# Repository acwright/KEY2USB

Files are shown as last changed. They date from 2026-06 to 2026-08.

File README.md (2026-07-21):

KEY2USB
=======

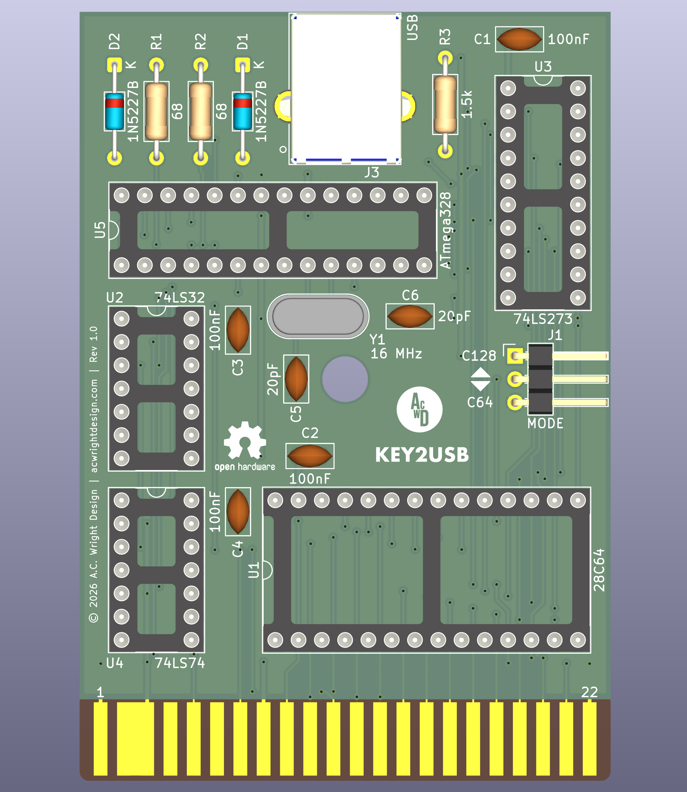
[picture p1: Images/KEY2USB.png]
KEY2USB


A non-invasive **Commodore 64** expansion port cartridge that lets the machine's own physical keyboard act as a **USB HID keyboard** for a connected PC running the VICE emulator. Plug it in, power on the C64, connect a USB cable — no case modification, no soldering into the keyboard.

---

## Table of Contents

- [Overview](#overview)
- [Compatibility](#compatibility)
- [Quick Start](#quick-start)
- [Architecture](#architecture)
- [Mode Jumper](#mode-jumper)
- [Hardware](#hardware)
  - [KEY2USB Board](#key2usb-board)
    - [Revision History](#revision-history)
- [Firmware](#firmware)
- [VICE Setup](#vice-setup)
  - [Joysticks](#joysticks)
  - [Verifying your setup](#verifying-your-setup)
  - [VIC-20 (xvic)](#vic-20-xvic)
- [Software](#software)
- [CAD](#cad)
- [Production](#production)
- [Schematics](#schematics)
- [Libraries](#libraries)
- [Bill of Materials](#bill-of-materials)
- [Purchase](#purchase)
- [License](#license)

---

## Overview

**KEY2USB** is a C64 cartridge that solves a specific problem: when running the VICE emulator on a PC alongside a real Commodore 64, you can't easily use the C64's authentic keyboard as a USB input device without modifying the machine. KEY2USB plugs into the expansion port and bridges the C64's keyboard matrix — read by the C64's own 6502 — to a USB HID keyboard interface, using no invasive hardware modifications.

Nothing inside the machine is touched. The cartridge takes over the C64 on power-up, scans the keyboard matrix itself, and reports every make/break to the PC as a standard USB HID boot keyboard. Power comes from the expansion port; the only cable is USB.

## Compatibility

| Machine | Supported | Notes |
|---|---|---|
| **Commodore 64** (all revisions) | Yes | Primary target |
| **Commodore 64C** | Yes | Identical keyboard matrix |
| **Commodore 128 / 128D** | Yes | Runs in C64 mode — see below. Verified on real hardware |
| **Ultimate 64** | Yes | Verified on real hardware |

On a **C128**, the cartridge asserts `/EXROM`, which the C128 detects at reset and
uses to boot straight into C64 mode — so KEY2USB comes up on its own with no key
combination needed. The full C128 keyboard is *not* scanned: the extra keys
(numeric keypad, ESC, TAB, ALT, HELP, and the separate cursor pad) sit outside the
standard 8×8 matrix and are not reported. Every key the C128 shares with the C64
works normally.

If a particular C128 does not autostart, power on while holding the **C=** key to
force C64 mode.

## Quick Start

1. With the C64 **powered off**, insert KEY2USB into the expansion port.
2. Connect the USB cable to your PC. The device enumerates as a standard HID
   keyboard — no drivers needed.
3. Power on the C64. The `KEY2USB` splash screen appears; the cartridge has taken
   over the machine and is scanning the keyboard.
4. In VICE, set **Settings → Keyboard → Keyboard Mapping → Positional**. This step
   is mandatory — see [VICE Setup](#vice-setup).
5. Type on the C64. Keystrokes arrive at the PC.

While KEY2USB is running, the C64 is dedicated to being a keyboard — it does not
return to BASIC. Power off and remove the cartridge to use the machine normally.

## Architecture

- **ROM side**: A 28C64 EEPROM holds two 4K firmware banks. The bank and `/EXROM` state are selected together by a single `MODE` jumper, set to **C64** on shipping units — see [Mode Jumper](#mode-jumper).
- **Glue logic**: A 74LS32 (quad OR gate) generates a write strobe from `/IO1` + `R/W`; a 74LS273 (8-bit D flip-flop register) latches the key-event byte the 6502 firmware writes to `$DE00`; a 74LS74 (dual D flip-flop) provides a single `RDY` handshake flag.
- **USB side**: An ATmega328P-PU runs the [V-USB](https://www.obdev.at/products/vusb/index.html) software USB stack, polls the latch via the `RDY` flag, and sends 8-byte USB HID boot-protocol keyboard reports. A 16 MHz crystal clocks the MCU.
- **USB front end**: Two 68Ω series resistors on D+ and D−, two 1N5227B (3.6V) Zener diodes to clamp the lines to spec, and a 1.5kΩ D− pull-up to +5V to signal a low-speed USB device — no 3.3V rail needed.
- **PCB constraint**: 100% through-hole / DIP — no SMD parts.

The two sides share only a single byte-wide latch and one ready flag — no shared clock or bus timing requirements.

## Mode Jumper

The board carries a 3-pin `MODE` header (J1) that selects the EEPROM bank and the
`/EXROM` state together:

| Jumper position | EEPROM bank | `/EXROM` | Behavior |
|---|---|---|---|
| **C64** (GND) — *factory default* | Lower 4K | Asserted | Autostarts via the `CBM80` signature. On a C128, forces a boot into C64 mode. |
| **C128** (+5V) | Upper 4K | Released | Autostarts as a C128 external function ROM in native mode. |

**Assembled cartridges ship with the jumper set to C64 and the case closed over
it.** The C64 bank is the supported configuration; it covers the C64, C64C, Ultimate 64, 
and the C128 by way of C64 mode. There is no need to change it, and the case has no opening for it.

The C128 bank is retained for developers and the curious. It is stable for the
standard 8×8 matrix — the same key coverage the C64 bank provides — but it offers
no advantage over C64 mode, since scanning of the C128-only extended keys is
incomplete and disabled. Changing the jumper means opening the case, and is
entirely at your own discretion.

## Hardware

This repository contains the KiCad 10.0 PCB design for the KEY2USB board.

### KEY2USB Board
`Hardware/`

A single cartridge PCB hosting the ROM, glue logic, and USB MCU. Provides:

- **ROM**: 28C64 EEPROM (DIP-28) preloaded with the keyboard-scan firmware
- **Write strobe**: 74LS32 quad OR gate — asserts `WRSTB` from `/IO1` + `R/W`
- **Key-event latch**: 74LS273 octal D flip-flop register — captures the byte written to `$DE00`
- **Handshake flag**: 74LS74 dual D flip-flop — one half as the `RDY`/`/CLRRDY` flag
- **USB MCU**: ATmega328P-PU (DIP-28) running V-USB, reads the latch, emits USB HID reports
- **Crystal**: 16 MHz THT crystal + 2× 20pF load capacitors
- **USB front end**: USB Type B connector, 68Ω series resistors, 1N5227B Zener clamps, 1.5kΩ D− pull-up
- **Mode select**: 3-pin 2.54mm jumper header — set to C64 at the factory (GND, asserts `/EXROM`, lower 4K EEPROM bank); see [Mode Jumper](#mode-jumper)
- **Bus connection**: 44-pin C64 expansion port edge connector
- **Power**: Drawn from the C64's own +5V via the expansion port

#### Revision History

**Rev 1.0**

- Initial release.

## Firmware

Both firmwares are implemented in `Firmware/` (see `Firmware/README.md` for build,
flash, and layout details). Set VICE's keyboard mapping to **Positional** — see
[VICE Setup](#vice-setup).

**6502 side (C64 bank — the shipping configuration):**
- Autostart via the `CBM80` signature, take over the machine, and draw a centered `KEY2USB` splash on the 40-column screen.
- Scan the 8×8 keyboard matrix directly via CIA #1 (`$DC00`/`$DC01`) for raw make/break events and modifier state — no KERNAL buffer.
- Scan **both joystick ports** on the same CIA #1 ports (they share the matrix lines, so no extra hardware is involved).
- On any key or joystick state change, write a one-byte event to `$DE00`.

The upper bank holds the C128 native-mode firmware, which autostarts from a
`CBM` / `$01` external function ROM header and scans the same 8×8 matrix. Extended-key
scanning via `$D02F` is present in the source but gated behind a build flag and not
compiled in — it is unverified on hardware. See `Firmware/Cart/README.md`.

**ATmega328/328P side:**
- Poll `RDY`; on set, read the key byte from `PINC`/`PINB`, pulse `/CLRRDY`.
- Run V-USB (low-speed USB 1.1); translate to USB HID usages and send an 8-byte boot-protocol keyboard report.
- Configured as a self-powered USB device.

## VICE Setup

One setting trips people up every time, so set it before anything else:

- **Keyboard mapping must be Positional, not Symbolic.** In VICE:
  **Settings → Keyboard → Keyboard Mapping → Positional**. This is the single
  most common first-time setup mistake — if keys look wrong, check this first.
  The reason is worth understanding, because it explains the whole signal path:

  A USB keyboard never transmits characters. Press `A` and it sends HID usage
  `0x04`; the USB spec names that "Keyboard a and A", but the name is only
  documentation — the code means *"the key where a US keyboard has A"*. Your OS
  decides it is an `A` by applying the selected layout. On AZERTY the same key
  sends the same `0x04` and the OS renders `Q`.

  KEY2USB is positional end to end for exactly that reason. The 6502 detects a
  key by matrix position (`col*8 + row`) and never computes a character; the
  ATmega looks that keyID up in `keymap.h` and emits the HID usage for the PC key
  in the corresponding physical spot; VICE's Positional keymap maps PC positions
  back onto C64 matrix positions. Positions in, positions through, positions out
  — nothing resolves to a character until VICE finally does it.

  Symbolic breaks that chain by inserting a translation. Press **SHIFT + 2**,
  which is `"` on a C64. The cartridge sends shift plus the position code for
  `2`; the host applies its US layout and concludes you typed `@`. Symbolic then
  asks "which C64 key produces `@`?" and presses that one — wrong. Positional
  ignores the character entirely, sees "physical shift + physical 2", and gives
  you the `"` you actually pressed. The keystroke arrived correctly either way;
  Symbolic just did an unwanted extra translation using a PC layout that does
  not match a C64's.
- USB HID reports are sent as a standard boot-protocol keyboard — no special
  VICE driver or configuration is needed beyond the keymap.

### Joysticks

Both joystick ports are scanned by the cartridge and arrive at the host as
**ordinary keystrokes**, so VICE has to be told which keys mean "joystick".
Everything lives on the numeric keypad, split so the two ports cannot collide:

**Port 2** — the easy one, no configuration at all:

> **Settings → Joystick → Joystick Port #2 → Numpad**

VICE's built-in Numpad device already maps keypad digits (`8/2/4/6` for
directions, `7/9/1/3` for diagonals, `0`/`5` for fire), and the cartridge's
port-2 mapping was chosen to match it exactly.

**Port 1** — needs a keyset, because Numpad can only serve one port:

> **Settings → Joystick → Joystick Port #1 → Keyset A**, then
> **Configure Keyset A**:

| Direction | Key |
|---|-----|
| North | Keypad **−** |
| South | Keypad **+** |
| West  | Keypad **/** |
| East  | Keypad **&ast;** |
| Fire  | Keypad **enter** |

Port 1 uses keypad *symbols* rather than digits or function keys for two
reasons: the digits are already claimed by the Numpad device serving port 2,
and the function-key row proved unreliable — F12 was silently undeliverable on
a macOS + GTK3 VICE host, with no identifiable cause. The symbols are untouched
by both.

### A caveat worth knowing

A held joystick direction grounds a line in the keyboard matrix, so it also
**phantom-presses real keys** — exactly as it does on a real C64. This is
inherent to the wiring, not a firmware choice, and it is left in place so the
cartridge behaves like the bare machine.

It hits **port 1** hardest: a held direction grounds a matrix *row*, pressing
all 8 keys in it — which includes RETURN, INST/DEL and CLR/HOME. Expect stray
keystrokes while a port-1 direction is held. **Port 2 is the one to use in
practice**; it grounds a column instead, which only aliases if you are also
pressing a key in that same column.

### Verifying your setup

`Software/key2usbtest.prg` shows live joystick state for both ports plus the
last keys received, so you can confirm the cartridge and your VICE
configuration in one place. See [Software/](Software/).

### VIC-20 (`xvic`)

The cartridge also drives VICE's VIC-20 emulator, with the same **Positional**
setting and no keymap changes. This works because VICE's two positional keymaps
are the same map in different coordinates — `VIC20/gtk3_pos.vkm` states the
relationship outright:

    # to convert from C64 to VIC20:
    # change rows 7 -> 0, 0 -> 7
    # change columns 7 -> 3, 3 -> 7

Applying that permutation and diffing the two files (VICE 3.x, GTK3, US layout)
gives:

| | |
|---|---|
| Host keysyms in each map | 151 / 151 |
| Present in one but not the other | 0 |
| Agree under the permutation | 150 |
| Differ | 1 |

The lone difference is cosmetic: `>` sits at matrix position `5 4` in both, but
carries shiftflag `1` on the C64 ("combined with shift") and `8` on the VIC-20
("can be shifted or not"). The cartridge sends the physical `.` key and physical
SHIFT as separate events, so both yield `>` regardless. The RESTORE entries
(`Page_Up` / `F12` / `Prior`) and all twenty joyport keypad entries are identical.

Both emulators therefore consume the same host keys and route them to the
same-labelled machine keys. `keymap.h` is built as the inverse of the C64
positional map, which makes it equally the inverse of the VIC-20 one.

Two caveats:

- This was established by comparing the shipped keymap files, not by a hardware
  session on `xvic`. The mapping is confirmed; end-to-end behaviour is not.
- **The VIC-20 has only one control port.** Point the cartridge's port-2 mapping
  (the keypad digits, via the Numpad device) at it; the port-1 keyset has nothing
  to connect to.

## Software
`Software/`

Host-side test software. `key2usbtest.prg` runs inside VICE and shows live
joystick state for both ports plus the last keystrokes received, so you can
verify a cartridge and your VICE configuration in one place. Build with
`make` (requires `petcat`, which ships with VICE) or use the prebuilt `.prg`.
See [Software/README.md](Software/README.md).

## CAD
`CAD/`

3D models and render images for the KEY2USB board.

## Production
`Production/`

JLCPCB-ready fabrication files, BOM, and component positions for PCB fabrication.

## Schematics
`Schematics/`

PDF schematic for the KEY2USB board.

## Libraries
`Libraries/`

Custom KiCad symbol and footprint libraries, including the C64 expansion port edge connector footprint and the USB Type B connector footprint.

## Bill of Materials

| Reference | Qty | Value | Description | Digikey |
|---|-----|---|---|---|
| C1, C2, C3, C4 | 4 | 100nF | Ceramic disc capacitor — IC bypass | [478-5732-ND](https://www.digikey.com/en/products/filter?keywords=478-5732-ND) |
| C5, C6 | 2 | 20pF | Ceramic disc capacitor — crystal load | [478-7724-ND](https://www.digikey.com/en/products/filter?keywords=478-7724-ND) |
| D1, D2 | 2 | 1N5227B | 3.6V Zener diode, DO-35 — USB line clamp | [1N5227B-ND](https://www.digikey.com/en/products/filter?keywords=1N5227B-ND) |
| J1 | 1 | MODE | 3-pin 2.54mm header + jumper cap — mode select, factory-set to C64 | [S1121EC-03-ND](https://www.digikey.com/en/products/filter?keywords=S1121EC-03-ND) |
| J2 | 1 | C64 EXP PORT | C64 expansion port edge connector (44-pin, 3.96mm pitch) | |
| J3 | 1 | USB | USB Type B connector, through-hole (UJ2-BH-BL1-TH) | [102-5886-ND](https://www.digikey.com/en/products/filter?keywords=102-5886-ND) |
| R1, R2 | 2 | 68Ω | Resistor, 1/4W — USB D+ / D− series | [S68CACT-ND](https://www.digikey.com/en/products/filter?keywords=S68CACT-ND) |
| R3 | 1 | 1.5kΩ | Resistor, 1/4W — USB D− pull-up to +5V | [S1.5KCACT-ND](https://www.digikey.com/en/products/filter?keywords=S1.5KCACT-ND) |
| U1 | 1 | 28C64 | 8K×8 EEPROM, DIP-28 — holds C64 and C128 firmware banks | [AT28C64B-15PU-ND](https://www.digikey.com/en/products/filter?keywords=AT28C64B-15PU-ND) |
| U2 | 1 | 74LS32 | Quad 2-input OR gate, DIP-14 — generates write strobe | [296-1658-5-ND](https://www.digikey.com/en/products/filter?keywords=296-1658-5-ND) |
| U3 | 1 | 74LS273 | 8-bit D flip-flop register, DIP-20 — key-event latch | [296-1657-5-ND](https://www.digikey.com/en/products/filter?keywords=296-1657-5-ND) |
| U4 | 1 | 74LS74 | Dual D flip-flop, DIP-14 — RDY handshake flag | [296-1668-5-ND](https://www.digikey.com/en/products/filter?keywords=296-1668-5-ND) |
| U5 | 1 | ATmega328P-PU | 8-bit AVR MCU, DIP-28 — V-USB and HID firmware | [ATMEGA328-PU-ND](https://www.digikey.com/en/products/filter?keywords=ATMEGA328-PU-ND) |
| Y1 | 1 | 16 MHz | Crystal, through-hole — ATmega328P clock | [3155-16M20P2/49US-ND](https://www.digikey.com/en/products/filter?keywords=3155-16M20P2/49US-ND) |

## Purchase

KEY2USB is available as a kit on Tindie for those who would rather not order
boards from a fab and source parts themselves.



## License

Hardware designs are released under the [CERN Open Hardware Licence Version 2 – Permissive](https://ohwr.org/cern_ohl_p_v2.txt).

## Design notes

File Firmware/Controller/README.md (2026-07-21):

KEY2USB — Controller (ATmega328/328P)
=====================================

Bare-metal AVR firmware that turns the KEY2USB cartridge into a **USB HID boot
keyboard** using [V-USB](https://www.obdev.at/products/vusb/). It reads C64/C128
key events from the 74LS273 latch (gated by the `RDY` flag), translates each
`keyID` to a USB HID usage, and sends 8-byte boot-keyboard reports.

Why bare-metal (no Arduino)
---------------------------
V-USB bit-bangs USB in software and needs tight, deterministic interrupt timing.
This is a frameworkless `avr-gcc` build. The V-USB stack is vendored in
`lib/usbdrv/`; the project config is `include/usbconfig.h`.

Layout
------
    include/usbconfig.h   V-USB configuration (HID boot keyboard, D+ = PD2/INT0)
    src/main.c            report loop, latch handshake, HID descriptor
    src/protocol.h        event-byte contract + pin helpers (mirrors Cart.inc)
    src/keymap.h          keyID -> HID usage table (editable)
    lib/usbdrv/           vendored V-USB
    fuses.cfg             fuse values for a 16 MHz crystal

Build & flash (PlatformIO)
--------------------------
    pio run                    # build (default env: atmega328)
    pio run -e atmega328p      # build for a 328P
    pio run -t upload          # flash CODE via minipro (uses the env's chip)

`platformio.ini` defaults to **atmega328** (the non-P chip on the test PCB).
Upload writes program memory **and** the fuses (`fuses.cfg`) each time, so a
fresh chip is fully configured in one `pio run -t upload`.

Fuses (one-time)
----------------
For a 16 MHz crystal, no bootloader, ISP enabled, BOD off:

| Fuse  | Value | Meaning |
|---|---|---|
| LFUSE | `0xFF`| low-power crystal 8–16 MHz, slow rising power, CKDIV8 off |
| HFUSE | `0xDF`| SPIEN on, no bootloader (BOOTRST=1), reset enabled |
| EFUSE | `0xFF`| brown-out detector disabled |
| LOCK  | `0xFF`| unlocked |

`fuses.cfg` holds these in minipro's config format (keys `lfuse`/`hfuse`/`efuse`/
`lock`). **The critical one is LFUSE**: a factory-fresh 328 ships at `0x62`
(internal 8 MHz RC ÷8 = 1 MHz) and must become `0xFF` for the external 16 MHz
crystal, or V-USB will not run.

    # optional: read current values (also confirms the file format)
    minipro -p "ATMEGA328@DIP28" -c config -r current.cfg
    # write the fuses
    minipro -p "ATMEGA328@DIP28" -c config -w fuses.cfg

minipro drives the ZIF socket directly, so it can still reprogram a chip whose
fuses select the external crystal — setting LFUSE=0xFF is not a lock-out.

USB identity
------------
Uses obdev's free shared VID/PID for HID-class devices: `0x16c0/0x27db`
(product string `KEY2USB`). Fine for personal use; see V-USB's
`USB-IDs-for-free.txt` for the rules.

The keymap
----------
`src/keymap.h` maps each `keyID` to a USB HID usage:

- `0x00`      — ignored
- `0x01..0xDF`— normal key (placed in the 6-key report array)
- `0xE0..0xE7`— modifier (Left Ctrl … Right GUI), OR-ed into the modifier byte

The defaults are the **inverse of VICE's stock C64 positional keymap**
(`gtk3_pos.vkm`), and that inversion is the whole design of this table: a HID
usage is itself a *position* (`0x04` means "the key where a US keyboard has A",
not the letter A), so each entry answers "which PC key sits where this C64 key
sits?" — never "which character does this key type?". VICE's **Positional**
keymap then maps those PC positions back onto C64 matrix positions and the
round trip closes. Symbolic breaks it by translating to characters through a PC
layout; see the top-level README's [VICE Setup](../../README.md#vice-setup).

Non-obvious defaults that match VICE positional:

    C64 CTRL  -> HID Tab          C64 C=        -> HID Left Ctrl (modifier)
    C64 R/S   -> HID Escape       C64 CLR/HOME  -> HID Home
    C64 £     -> HID End          C64 =         -> HID Page Down
    C64 up    -> HID '\'          C64 left      -> HID '`'

Edit the table freely for other hosts/emulators. keyIDs 64–87 (C128 extended
keys) are unmapped by default — see the Cart README to enable that scan.

Joysticks
---------
Both joystick ports are scanned by the cartridge and arrive as ordinary key
events, so the host just sees keystrokes. Defaults:

| Port | keyIDs | Up | Down | Left | Right | Fire |
|---|---|----|---|---|---|---|
| 2 | 112–116| Keypad 8 | Keypad 2 | Keypad 4 | Keypad 6 | Keypad 0 |
| 1 | 120–124| Keypad − | Keypad + | Keypad / | Keypad &ast; | Keypad enter |

Port 1 avoids the function-key row because **F12 proved undeliverable on a
macOS + GTK3 VICE host** (verified 2026-07-19: F8–F11 all registered, F12 never
did — including pressed directly on the host keyboard with the cartridge
unplugged). The standard-function-keys setting, macOS symbolic hotkeys, VICE's
hotkey files and the SDL menu key were all ruled out; the root cause was never
found, so port 1 steers clear of that row entirely.

Keypad **digits** are equally unusable: VICE's Numpad device — the port-2
setting — claims KP 7/9/1/3 for diagonals and KP 0/5 for fire, so digits would
cross-trigger between the two ports. Only the symbols are free, and they sit
sensibly on the pad (`/` left of `*`, `−` above `+`).

Point VICE at them with **Settings → Joystick → Keyset A / Keyset B**, then
assign the keyset to the emulated port.

Both sets use usages that **no matrix key can produce**, which is deliberate.
A held port-1 direction grounds a row line and phantom-presses all 8 keys in
that row, so an earlier mapping to `W/S/A/D` was indistinguishable from the
stick's own crosstalk — pressing left emitted `A, D, G, J, L`, which is exactly
row 2 of the C64 matrix. F8–F12 and the keypad never appear in the keyboard
table above, so they are unambiguous.

Two things to know:

- **Keypad usages can depend on NumLock** on some hosts. If port 2 misbehaves,
  either switch NumLock on or retarget those five entries.
- The HID boot keyboard reports **6 non-modifier keys at once**, and
  `keyDown()` silently drops past six. This is why the cartridge scans the
  joysticks *before* the matrix: a held port-1 direction generates 8 phantom
  key events, which would otherwise claim every slot and starve the real
  joystick event. Port 1 remains inherently noisy — the phantoms are genuine
  C64 behaviour — so port 2 is the one to use in practice.

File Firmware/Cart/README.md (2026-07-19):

KEY2USB — Cartridge ROM (6502)
==============================

Autostart ROM for the KEY2USB expansion-port cartridge. It takes over the
C64/C128, shows a `KEY2USB` splash, then continuously scans the CIA#1 keyboard
matrix and both joystick ports, writing a make/break **event byte** to `$DE00`
(`/IO1`) on every transition. The 74LS273 latches the byte and the 74LS74 raises
`RDY` for the ATmega328 controller.

Two banks, one source
---------------------
The 28C64 (8K) is split by the `MODE` switch, which drives EEPROM `A12`:

| MODE | A12 | Bank | Autostart |
|---|-----|---|---|
| GND | 0 | lower 4K  | C64 (`CBM80`, forces C128 into C64 mode) |
| +5V | 1 | upper 4K  | C128 (function-ROM `CBM` signature) |

`Cart.asm` is assembled twice (the C128 build passes `--asm-define TARGET_C128`)
and the two 4K images are concatenated into the 8K `Cart.bin`. Only bus
`A0..A11` reach the EEPROM, so each 4K bank mirrors across the `$8000-$9FFF`
ROML window.

Build
-----
Requires [cc65](https://cc65.github.io/) (`cl65` on PATH).

    make            # -> Cart.bin (8192 bytes)
    make view       # hexdump Cart.bin
    make clean

Program the EEPROM
------------------
    make eeprom     # build, then program the AT28C64B via minipro

`make eeprom` runs `minipro -p "AT28C64B" -w Cart.bin`. Use minipro's plain
`AT28C64B` profile (confirm with `minipro -d AT28C64B`) — not the separate
`AT28C64B(Non-Standard)` entry. Override the device for a different part, e.g.
`make eeprom EEPROM="AM28C64B@DIP28"`.

Event byte protocol
-------------------
Written to `$DE00`:

    bit 7      1 = pressed (make), 0 = released (break)
    bits 6..0  keyID

| keyID | Source |
|---|---|
| `0..63` | C64 matrix, `col*8 + row` (the classic KERNAL "keyboard code") |
| `64..87`  | C128 extended keys (optional scan, off by default) |
| `112..116`| Joystick **port 2** — up, down, left, right, fire |
| `120..124`| Joystick **port 1** — up, down, left, right, fire |

The 6502 side reports switch positions only; the ATmega owns the keyID → USB
HID mapping, so joystick contacts arrive at the host as ordinary keystrokes.

Joysticks
---------
Both ports share CIA#1 with the keyboard — port 2 on port A (the column drive),
port 1 on port B (the row read). **No extra hardware is involved** — the DE9
ports were always on these lines.

Port A must be switched to inputs (`DDRA = $00`) before reading. While the
matrix scan owns it, `DDRA = $FF` makes PA0–PA4 push-pull outputs and a
grounded contact does *not* read back as low, so port 2 reads permanently idle
— this is why every stock C64 joystick routine clears `DDRA` first. Port B is
already an input. A short settle delay follows the DDR change, because as
inputs the lines rise only through the CIA's passive pull-ups against joystick
cable capacitance.

Because no column is driven during the read, a pressed key can never
phantom-press a joystick contact. The reverse crosstalk is inherent to the
wiring and is deliberately left alone so the cartridge behaves like the bare
machine:

- a held **port 2** direction grounds a column line, so keys in that column
  alias into other columns' row reads;
- a held **port 1** direction grounds a row line, so that row reads as pressed
  in *every* column — the classic "stick in port 1 breaks menus" behaviour.

In practice this only matters if you type while holding a direction.

C128 extended keys
------------------
The C128's extra keys (numeric keypad / ESC / TAB / ALT / HELP / cursor pad) are
read via `$D02F` as keyIDs `64 + kcol*8 + row`. This scan is experimental and
gated behind a `.define SCAN_EXTENDED` build flag in `Cart.asm`; it is **not**
compiled in by default. With it off, the C128 bank scans the standard 8×8 matrix
(the full C64-compatible key subset). To enable it, define the flag and add the
corresponding keyID 64+ entries to `Controller/src/keymap.h`.

Notes
-----
- RESTORE is wired to NMI (not in the matrix); the firmware installs a harmless
  NMI handler so RESTORE does not drop back to BASIC.
- Runtime key-state is kept in zero page. On the C128 the external-function-ROM
  memory config maps `$C000-$FFFF` to ROM, so 6502 scratch must live in low RAM
  / zero page to work on both machines.
- The splash uses a light-blue border / black background / white text so an
  attached monitor gives an obvious "cartridge is alive" indication; the
  cartridge is fully functional headless.
- `emit_event` must preserve `Y`: `process_column` holds its row index there
  across the call, while the pacing delay uses `Y` as its own counter. Getting
  this wrong emits every event after the first in a column as `keybase+1`
  (fixed in v1.1.0 — it was latent in v1.0, where two same-column keys changing
  within one 10 ms scan was rare enough to go unnoticed).

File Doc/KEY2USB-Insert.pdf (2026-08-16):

# KEY2USB K I T

Use your Commodore 64's own keyboard as a USB keyboard for VICE — no soldering into the machine, no case modification.
Thank you for your order! Everything you need is in this box: the PCB, all components, and a 3D-printed case. The two programmed chips — the 28C64 EEPROM (U1) and the ATmega328 (U5) — arrive pre-programmed and ready to run, so there is nothing to flash. All you need to supply is a soldering iron, solder, and side cutters. If anything is missing or damaged, email me and I'll make it right.

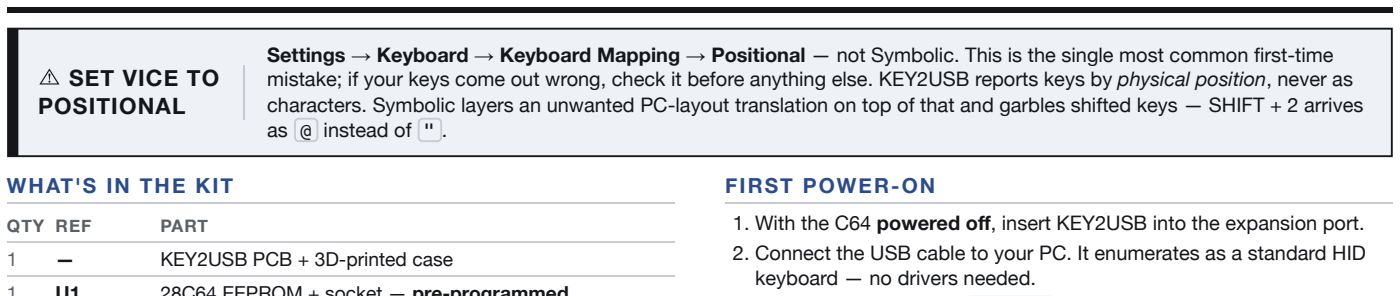
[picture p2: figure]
⚠ SET VICE TO POSITIONAL; as @ instead of " .; WHAT'S IN THE KIT; QTY REF; PART; KEY2USB PCB + 3D-printed case; FIRST POWER-ON; keyboard — no drivers needed.

Settings → Keyboard → Keyboard Mapping → Positional — not Symbolic. This is the single most common first-time mistake; if your keys come out wrong, check it before anything else. KEY2USB reports keys by physical position, never as characters. Symbolic layers an unwanted PC-layout translation on top of that and garbles shifted keys — SHIFT + 2 arrives

1 | U1 | 28C64 EEPROM + socket — pre-programmed
1 | U5 | ATmega328 MCU + socket — pre-programmed
3 | U2–U4 | 74LS32 (DIP-14), 74LS273 (DIP-20), 74LS74 (DIP-14) glue logic
3 | Y1, C5, C6 16 MHz crystal + 2× 20pF load caps
4 | C1–C4 | 100nF ceramic — IC bypass
2 | D1, D2 | 1N5227B 3.6V Zener — polarized
3 | R1–R3 | 2× 68Ω USB series, 1× 1.5kΩ D− pull-up
2 | J1, J3 | 3-pin MODE header + jumper cap, USB Type B connector
ASSEMBLY
All through-hole. Build shortest-to-tallest so parts sit flat. The two programmed chips get sockets; the three 74LS logic ICs solder directly down.
1. Resistors R1–R3 , then ceramic capacitors C1–C6 — neither is
| polarized.
2. Zener diodes D1 D2 — polarized. The band on the body must match the banded end of the silkscreen outline.
3. The two DIP-28 sockets at U1 and U5 , notch matching the silkscreen. Leave them empty for now.
4. U2 U3 U4 soldered straight down — check each notch against the silkscreen first; these are not socketed and are unpleasant to remove.
5. Crystal Y1 , MODE header J1 , then the USB Type B connector J3 — seat J3 fully flat; it takes the mechanical stress of the cable.
6. Trim all leads flush, then inspect for solder bridges — especially along the edge fingers and between adjacent IC pins.
7. Press the labeled U1 and U5 chips into their sockets last, notch matching, with no bent-under pins.
Before closing the case: fit the jumper cap on J1 in the C64 position (the GND side, marked on the silkscreen) — the supported setting, and covers every machine listed below. (The board's other firmware bank holds an unsupported C128 native-mode build, kept for the curious.)
COMPATIBILITY
Commodore 64 / 64C | Yes — primary target
Commodore 128 / 128D | Yes — boots straight into C64 mode
Ultimate 64 | Yes — verified on hardware

On a C128 the cartridge asserts /EXROM , so it comes up in C64 mode on its own; if one does not autostart, power on holding C= . Its extra keys (keypad, ESC, TAB, ALT, HELP, cursor pad) sit outside the standard 8×8 matrix and are not reported; every key it shares with the C64 works.

1. With the C64 powered off, insert KEY2USB into the expansion port.
2. Connect the USB cable to your PC. It enumerates as a standard HID
3. Power on the C64. The KEY2USB splash screen appears; the cartridge has taken over the machine and is scanning the keyboard.
4. In VICE, set Settings → Keyboard → Keyboard Mapping → Positional. This step is mandatory.
5. Type on the C64. Keystrokes arrive at the PC.
While KEY2USB is running the C64 is dedicated to being a keyboard and does not return to BASIC. Power off and remove the cartridge to use the machine normally.
JOYSTICKS IN VICE
Both joystick ports are scanned and arrive at the host as ordinary keypad keystrokes, so VICE must be told which keys mean "joystick."
Port 2 — no configuration needed beyond Settings → Joystick → Joystick Port #2 → Numpad. VICE's built-in Numpad device already matches the cartridge's port-2 mapping exactly.
Port 1 — needs a keyset, since Numpad can only serve one port. Set Joystick Port #1 → Keyset A, then Configure Keyset A:
DIRECTION | KEY
North | Keypad −
South | Keypad +
West | Keypad /
East | Keypad *
Fire | Keypad enter

Worth knowing: a held joystick direction grounds a line in the keyboard matrix, so it phantom-presses real keys — exactly as on a bare C64. Port 1 is hit hardest, grounding a whole matrix row (RETURN, INST/DEL, CLR/HOME), so expect stray keystrokes while a port-1 direction is held. Port 2 is the one to use. TROUBLESHOOTING

SYMPTOM | CHECK
Wrong characters | VICE keyboard mapping is set to Positional, not Symbolic.
No splash screen | Cartridge fully seated, C64 powered off when inserted. Then re-check IC orientation and bridged joints near U1 and the edge fingers.
No USB device | The C64 must be powered on — the cartridge is bus-powered. Then check Y1 and its 20pF caps, R1–R3, and the D1/D2 band orientation.

Joystick does nothing Port 2 set to Numpad; port 1 set to Keyset A and
| configured as above.

Software/key2usbtest.prg in the repository shows live joystick state and the last keys received — the quickest way to check a finished build.

Schematic, firmware source & full documentation: github.com/acwright/KEY2USB Store: tindie.com/stores/acwrightdesign · Support: acwrightdesign@gmail.com Hardware released under the CERN Open Hardware Licence v2 — Permissive.

| Stuck on a build? Please reach out before leaving a review — I'm happy to help.

— Aaron Wright

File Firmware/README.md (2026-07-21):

KEY2USB — Firmware
==================

Two independent firmwares that share exactly one thing: the **event byte**.

    Cart/         6502 autostart ROM for the 28C64 (C64 + C128 banks)
    Controller/   ATmega328/328P V-USB HID keyboard

    ┌──────────┐  scan matrix   ┌─────────┐  write $DE00   ┌─────────┐  RDY   ┌──────────┐  USB HID
    │ C64/C128 │ ─────────────► │  6502   │ ─────────────► │ 74LS273 │ ─────► │ ATmega328│ ───────►  PC
    │ keyboard │                │  ROM    │                │ + 74LS74│  latch │  (V-USB) │           (VICE)
    └──────────┘                └─────────┘                └─────────┘        └──────────┘

The 6502 ROM scans the keyboard matrix and writes one event byte to `$DE00`
per key transition; the 74LS273 latches it and the 74LS74 raises `RDY`. The
ATmega reads the latch, translates the keyID to a USB HID usage, and sends
boot-keyboard reports. The 6502 reports only matrix positions — the ATmega owns
the keyID → USB HID mapping.

Event byte (`$DE00` → latch → ATmega):

    bit 7      1 = pressed (make), 0 = released (break)
    bits 6..0  keyID   0..63    C64 matrix, col*8+row
                       64..87   C128 extended keys (optional scan)
                       112..116 joystick port 2 (up/down/left/right/fire)
                       120..124 joystick port 1 (up/down/left/right/fire)

Both joystick ports are scanned alongside the matrix — they already sit on
CIA#1, so this needs no extra hardware. Contacts are reported as ordinary key
events; `Controller/src/keymap.h` decides what they type.

Build and flash
---------------
    cd Cart && make eeprom          # build + program the 28C64
    cd Controller && pio run -t upload   # build + program the 328 (code + fuses)

See each subdirectory's README for details (linker/bank layout, fuses, keymap).

Notes
-----
- **VICE must use the Positional keymap**, not Symbolic. The path is positional
  end to end: the 6502 reports a matrix position, the ATmega emits the HID usage
  for the PC key in the matching physical spot, and Positional maps that back to
  a C64 matrix position. (HID usages are themselves positional — `0x04` means
  "the key where a US keyboard has A", not the letter A; the host layout decides
  the character.) Symbolic inserts a character translation using a PC layout and
  produces the wrong C64 key even though every keystroke arrived correctly. Full
  explanation in the top-level README's [VICE Setup](../README.md#vice-setup).
- The keyID → USB HID table lives in `Controller/src/keymap.h` and is easy to
  retarget for other hosts/emulators.

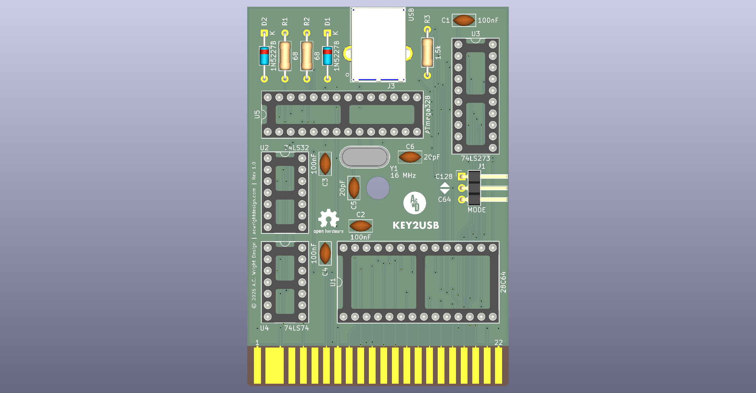
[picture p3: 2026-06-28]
CAD/Images/Front.png

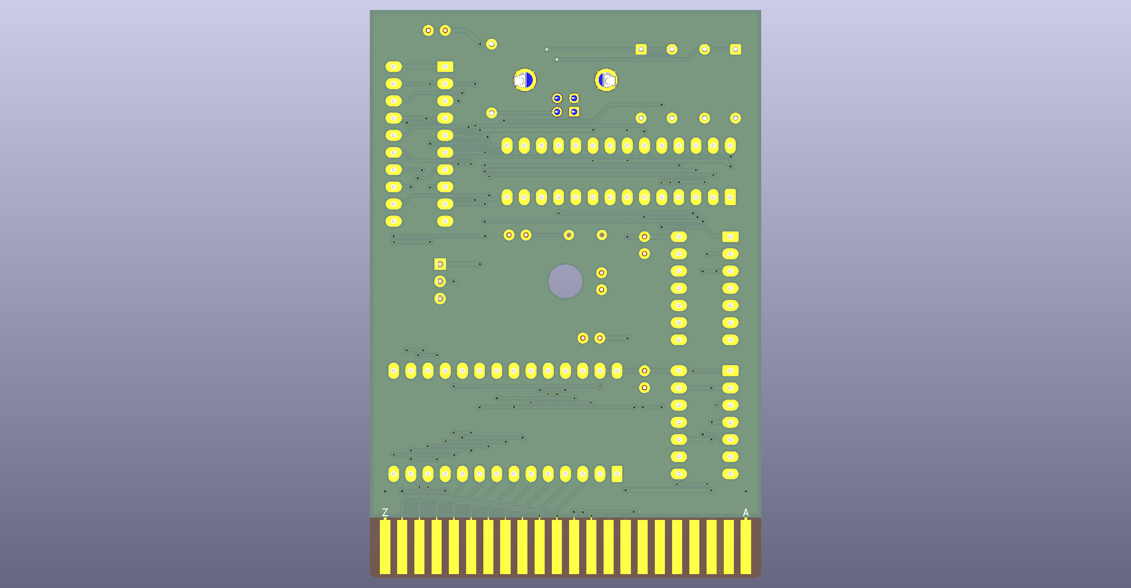
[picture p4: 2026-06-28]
CAD/Images/Back.png

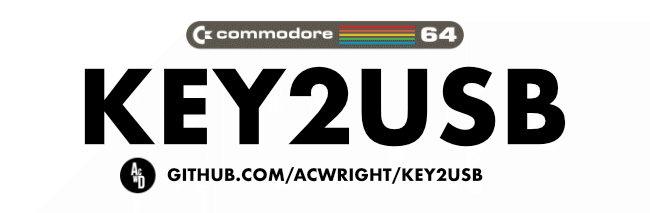
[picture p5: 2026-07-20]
CAD/Label/Label.png

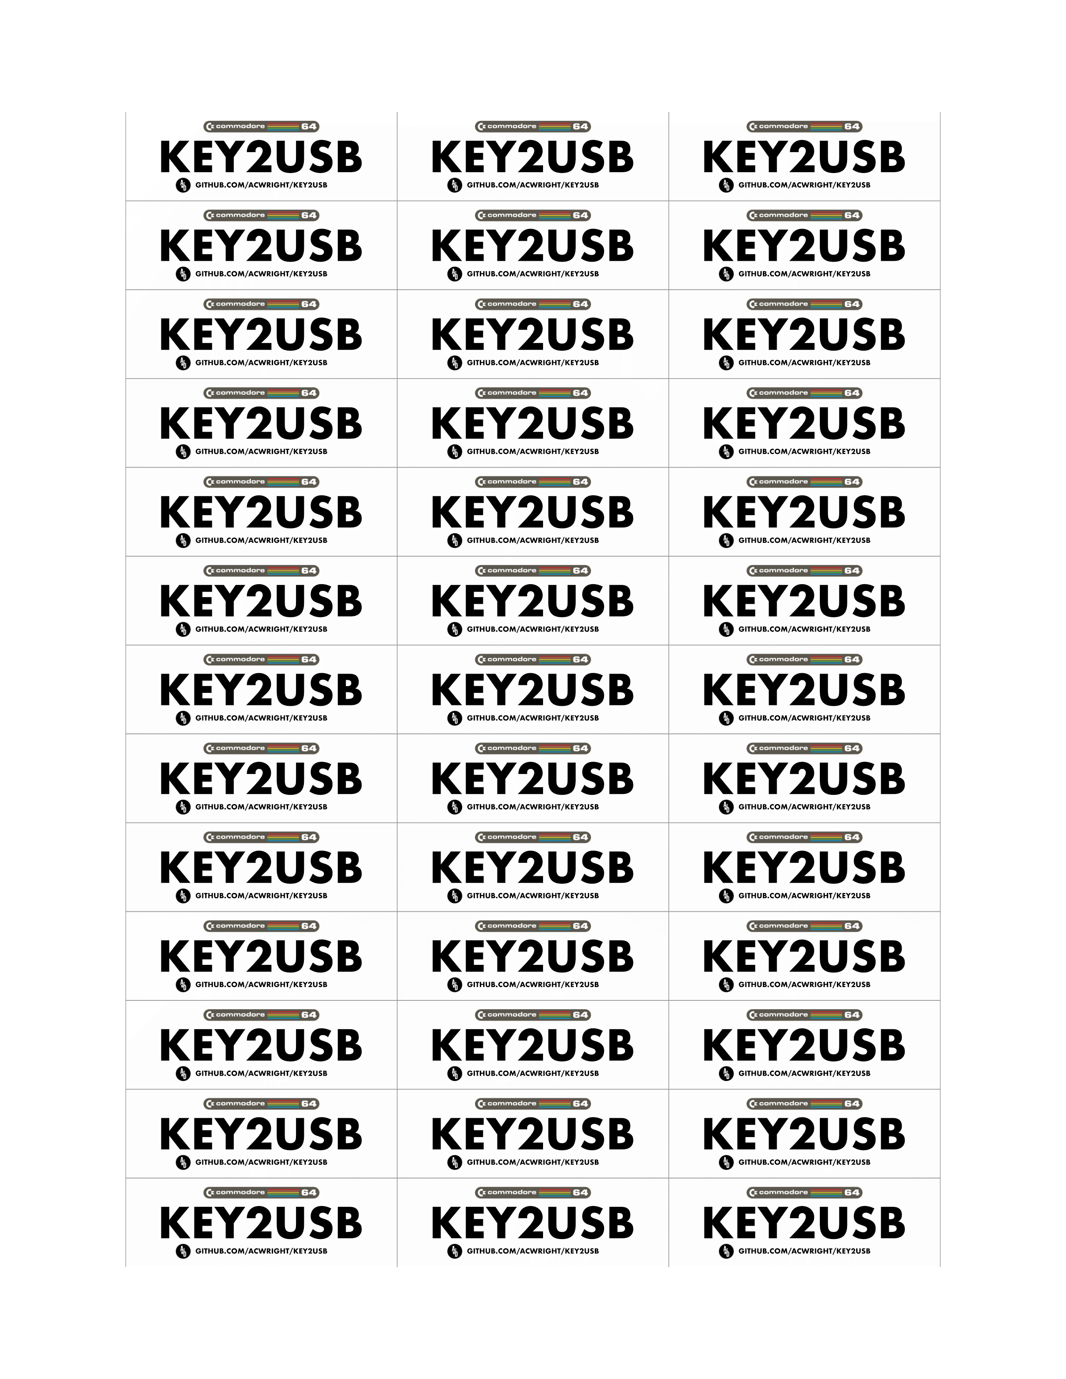
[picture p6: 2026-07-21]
CAD/Label/Label - Layout.png

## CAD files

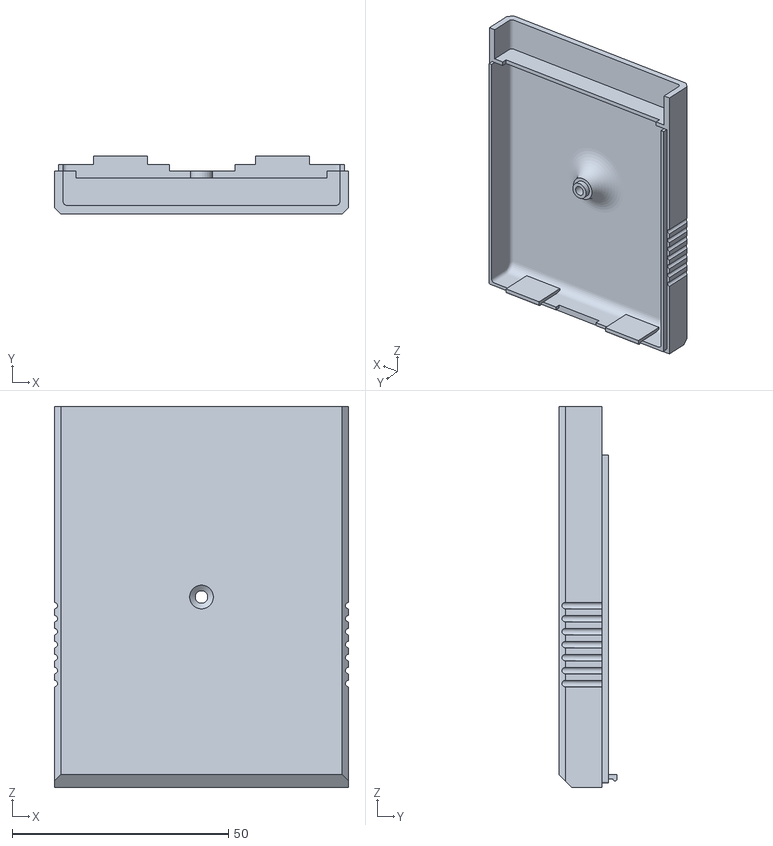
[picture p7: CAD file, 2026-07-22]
CAD/Case/Bottom.stl
68.0 x 13.5 x 88.0

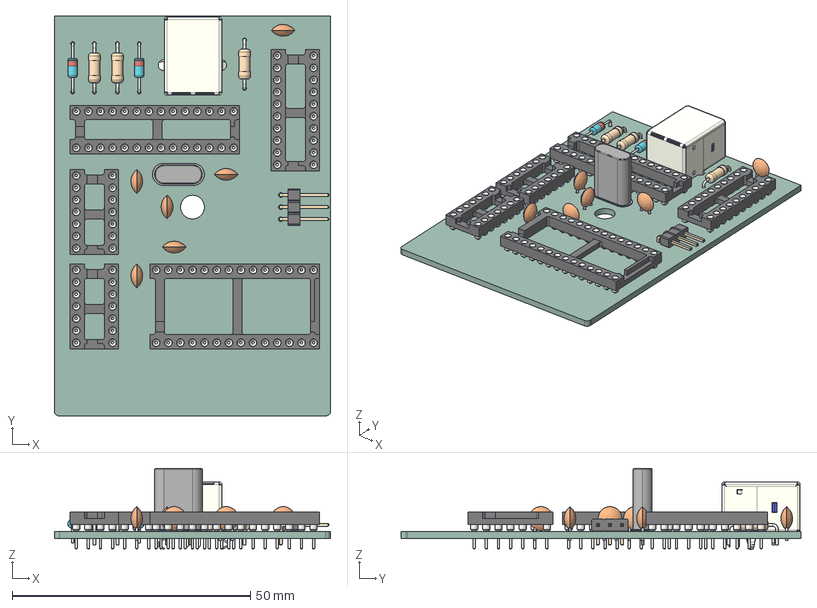
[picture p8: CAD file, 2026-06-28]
CAD/Models/KEY2USB.step
57.9 x 83.9 x 17.0 mm
DIP_14_W762mm_Socket x 2
D_DO-35_SOD27_P10.16mm_Horizontal x 2
DIP_28_W1524mm_Socket
DIP_28_W762mm_Socket
PinHeader_1x03_P254mm_Horizontal
C_Disc_D50mm_W25mm_P250mm x 6
Crystal_HC49-U_Vertical
R_Axial_DIN0207_L63mm_D25mm_P1016mm_Horizontal x 3
CUI_DEVICES_UJ2-BH-BL1-TH
DIP_20_W762mm_Socket
KEY2USB_PCB

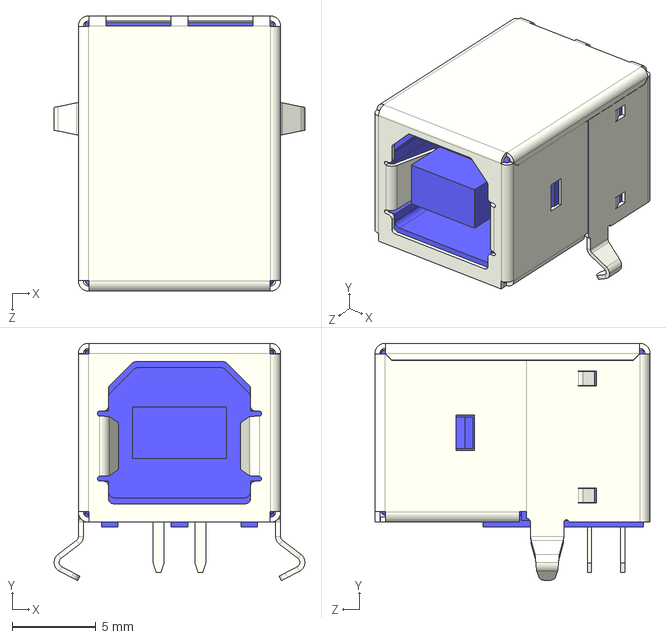
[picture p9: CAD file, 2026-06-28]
Models/UJ2-BH-BL1-TH.step
15.0 x 14.2 x 16.5 mm

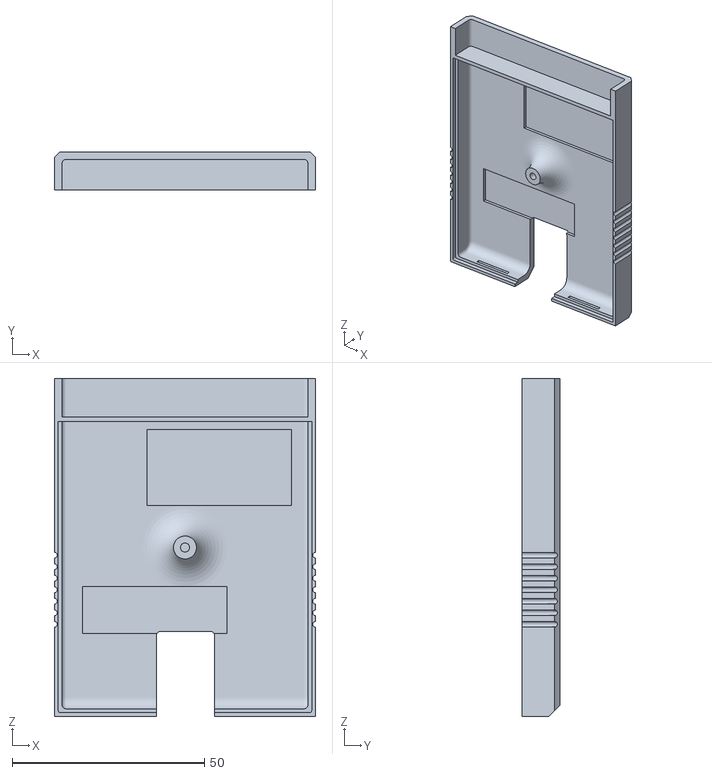
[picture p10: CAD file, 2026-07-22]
CAD/Case/Top.stl
68.0 x 10.0 x 88.0

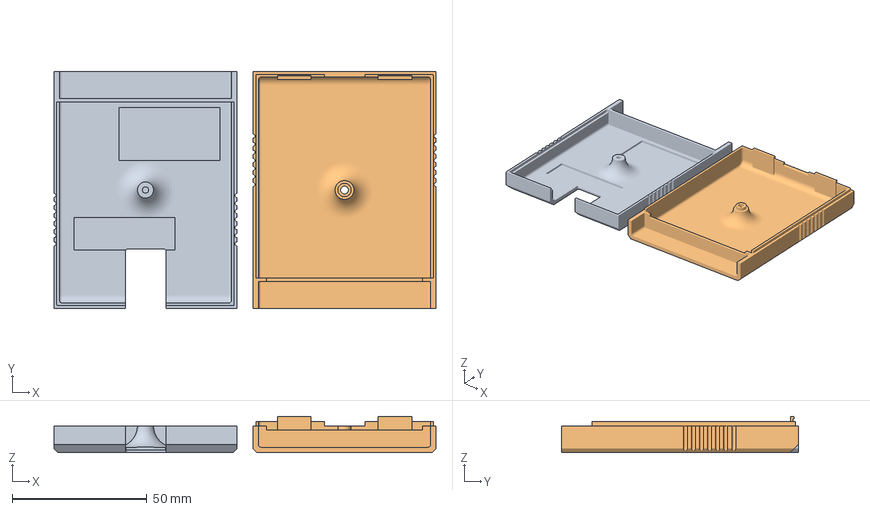
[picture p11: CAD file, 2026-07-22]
CAD/Case/Case.3mf
142.0 x 88.0 x 13.5 mm
Top.stl
Bottom.stl

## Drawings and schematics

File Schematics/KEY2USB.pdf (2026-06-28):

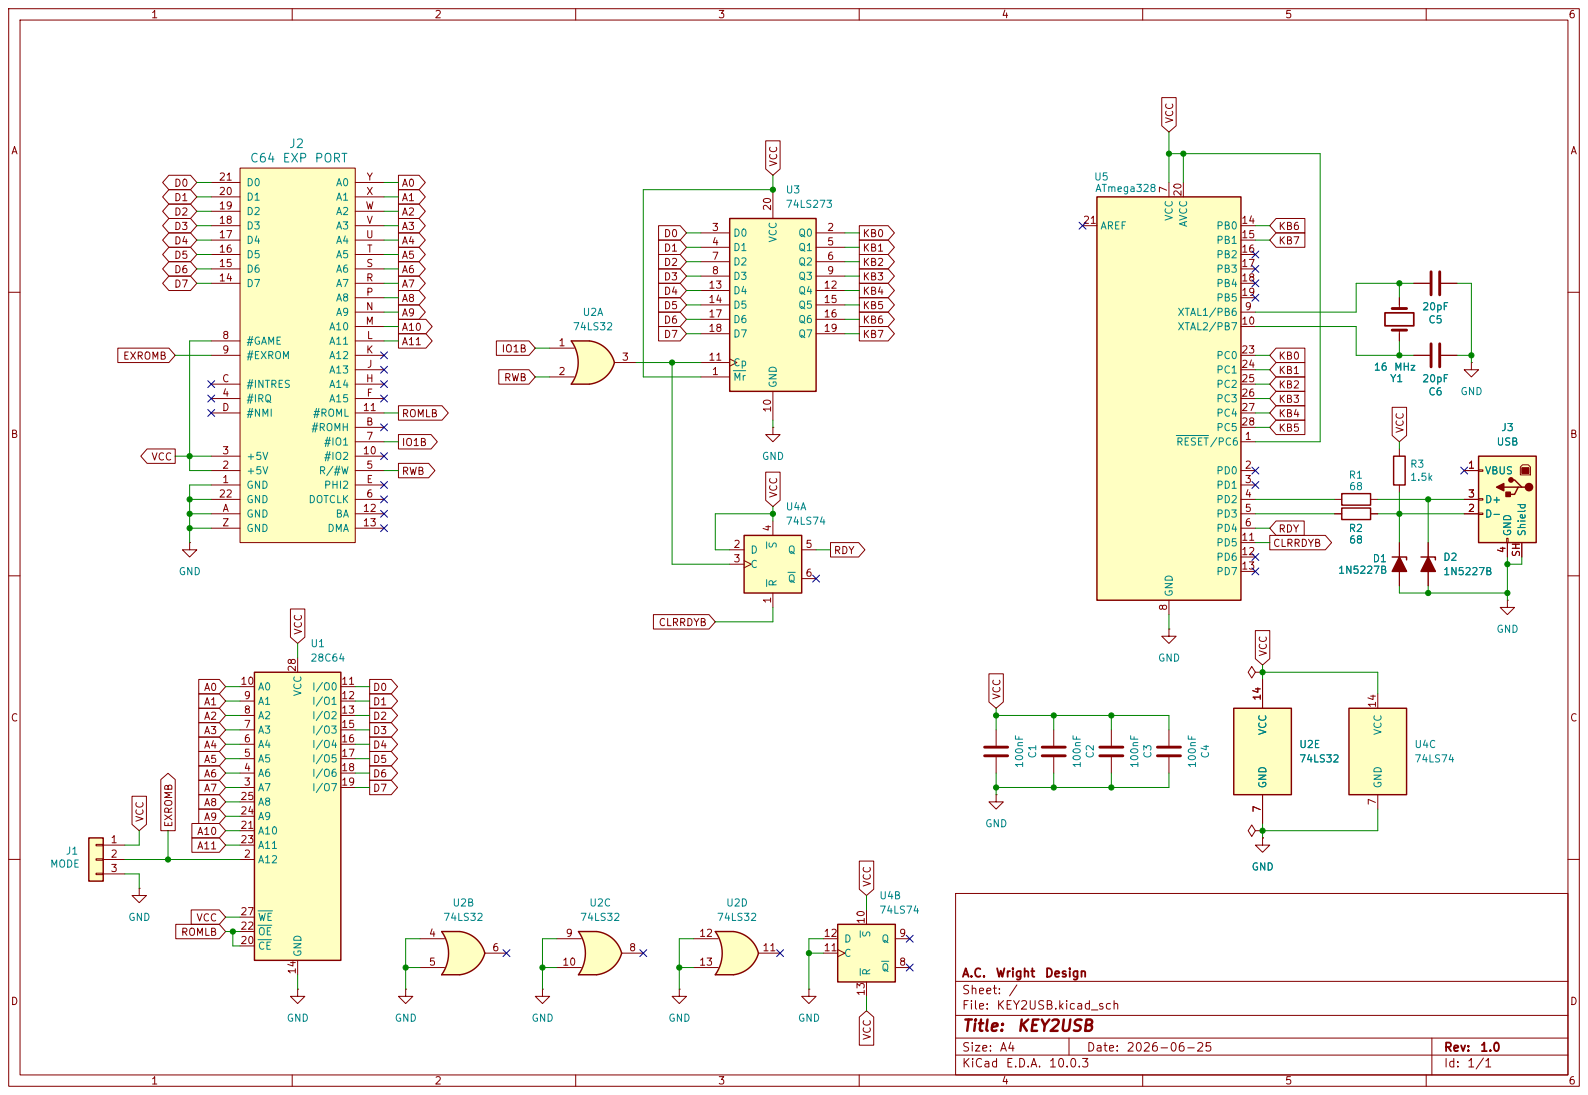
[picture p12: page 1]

Size: A4 | Rev: 1.0
KiCad E.D.A. 10.0.3 | Id: 1/1

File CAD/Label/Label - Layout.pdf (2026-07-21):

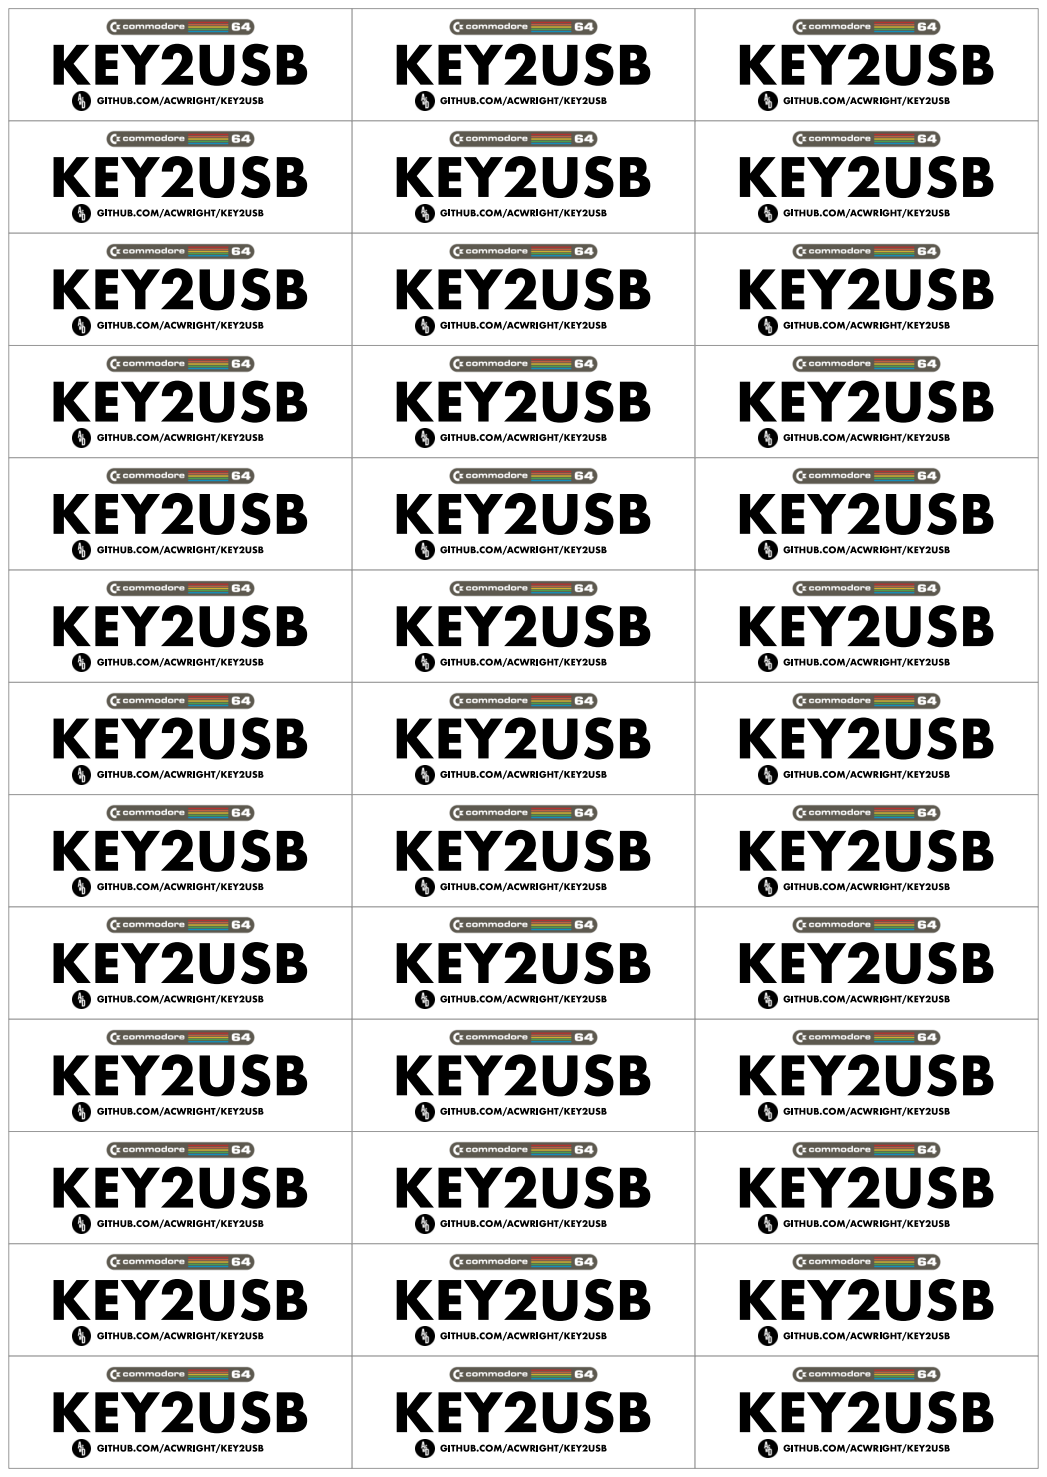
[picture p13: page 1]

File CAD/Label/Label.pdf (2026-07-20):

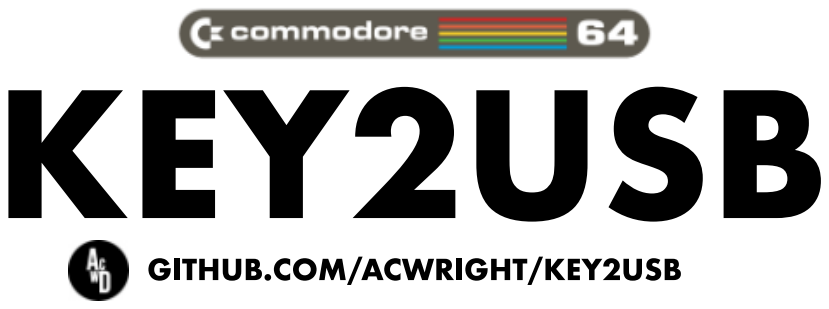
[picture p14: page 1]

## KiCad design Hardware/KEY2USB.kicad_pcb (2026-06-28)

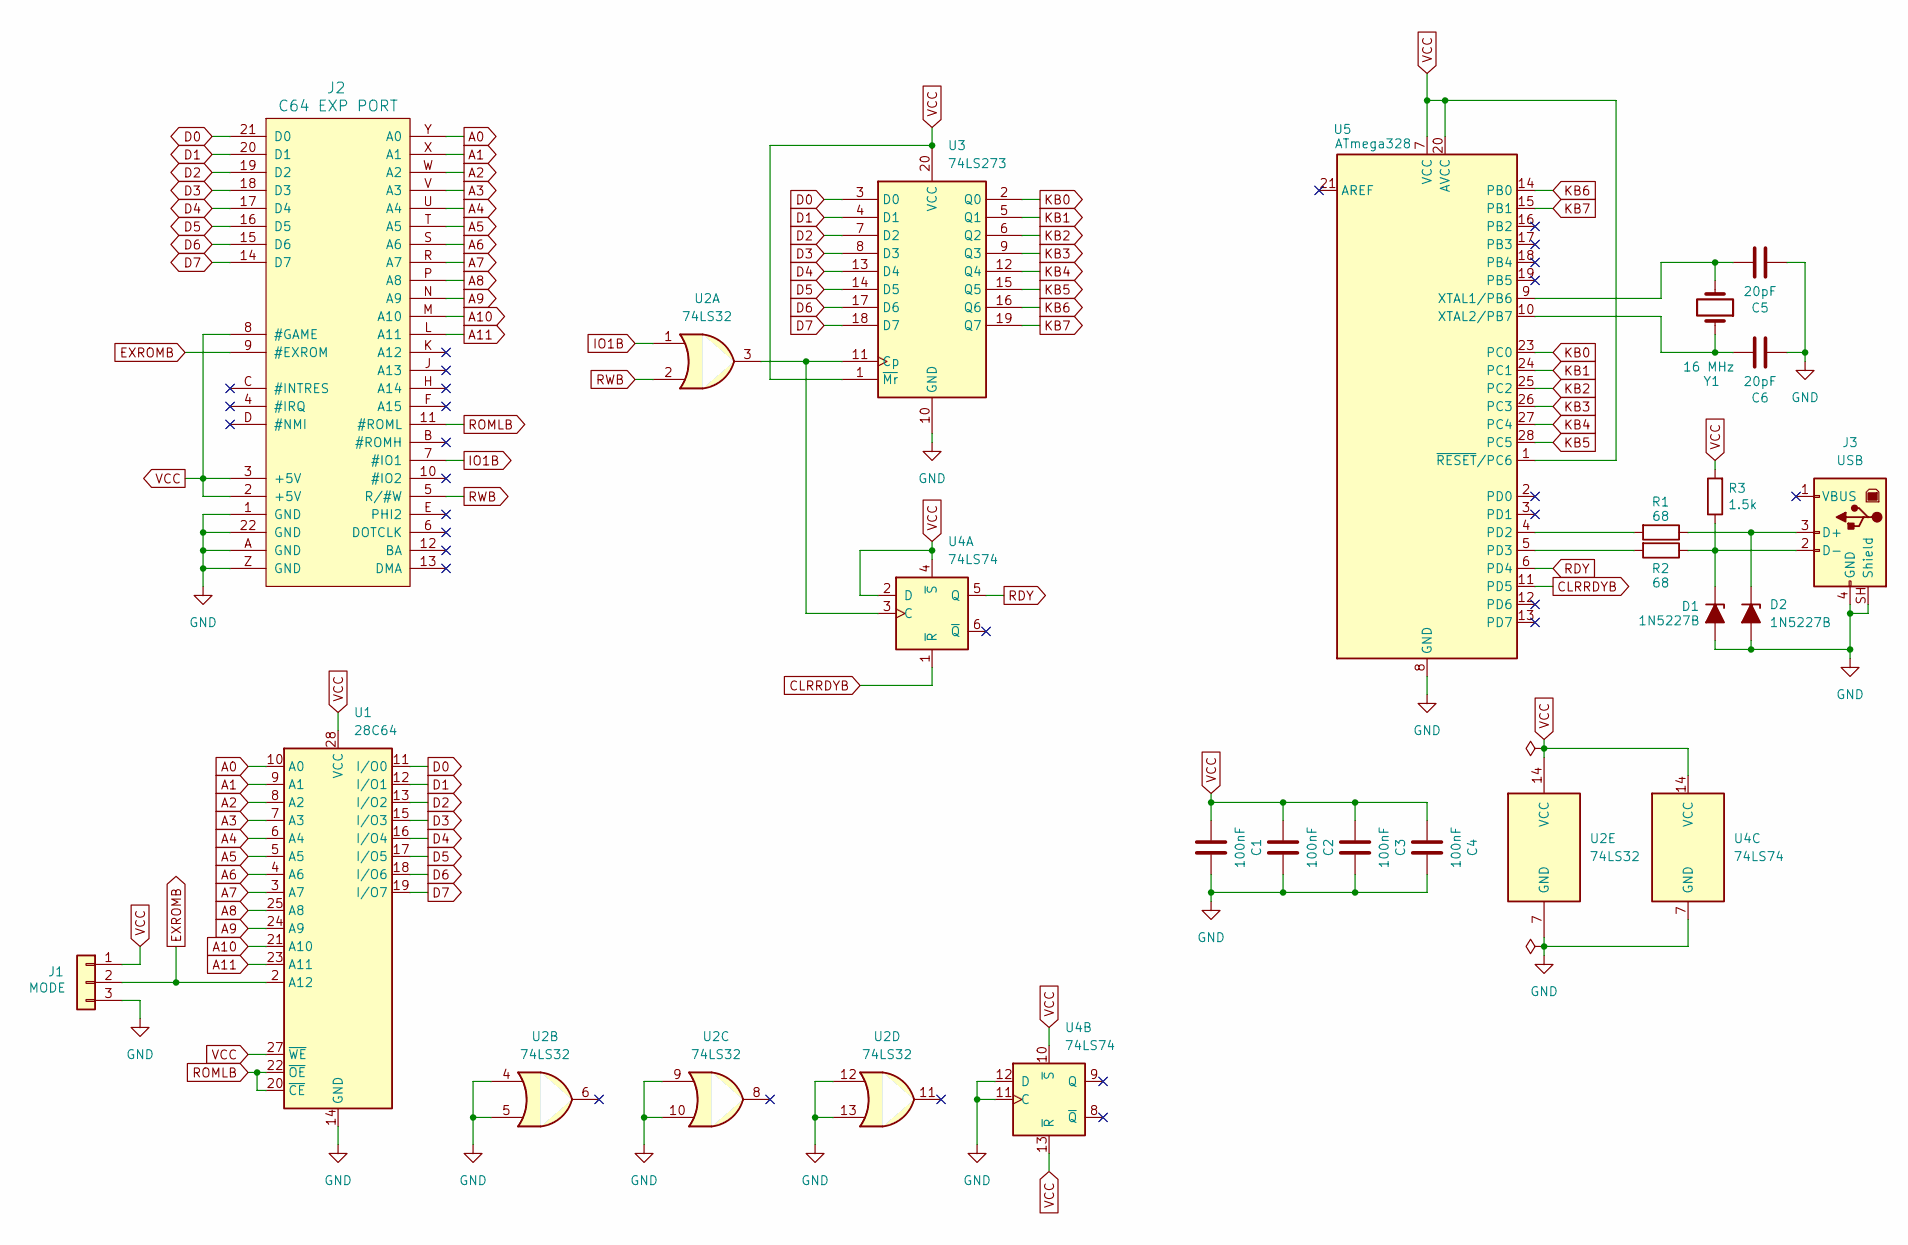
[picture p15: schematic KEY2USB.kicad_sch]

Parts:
C1, C2, C3, C4: 100nF; C_Disc_D5.0mm_W2.5mm_P2.50mm; Digikey 478-5732-ND
C5, C6: 20pF; C_Disc_D5.0mm_W2.5mm_P2.50mm; Digikey 478-7724-ND
D1, D2: 1N5227B; D_DO-35_SOD27_P10.16mm_Horizontal; Digikey 1N5227B-ND
J1: MODE; PinHeader_1x03_P2.54mm_Horizontal; Digikey S1121EC-03-ND
J2: C64 EXP PORT; C64_EXPANSION_PORT
J3: USB; UJ2-BH-BL1-TH; Digikey 102-5886-ND
R1, R2: 68; R_Axial_DIN0207_L6.3mm_D2.5mm_P10.16mm_Horizontal; Digikey S68CACT-ND
R3: 1.5k; R_Axial_DIN0207_L6.3mm_D2.5mm_P10.16mm_Horizontal; Digikey S1.5KCACT-ND
U1: 28C64; DIP-28_W15.24mm_Socket_LongPads; Digikey AT28C64B-15PU-ND
U2: 74LS32; DIP-14_W7.62mm_Socket_LongPads; Digikey 296-1658-5-ND
U3: 74LS273; DIP-20_W7.62mm_Socket_LongPads; Digikey 296-1657-5-ND
U4: 74LS74; DIP-14_W7.62mm_Socket_LongPads; Digikey 296-1668-5-ND
U5: ATmega328; DIP-28_W7.62mm_Socket_LongPads; Digikey ATMEGA328-PU-ND
Y1: 16 MHz; Crystal_HC49-U_Vertical; Digikey 3155-16M20P2/49US-ND

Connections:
A0: J2.Y (A0), U1.10 (A0)
A1: J2.X (A1), U1.9 (A1)
A2: J2.W (A2), U1.8 (A2)
A3: J2.V (A3), U1.7 (A3)
A4: J2.U (A4), U1.6 (A4)
A5: J2.T (A5), U1.5 (A5)
A6: J2.S (A6), U1.4 (A6)
A7: J2.R (A7), U1.3 (A7)
A8: J2.P (A8), U1.25 (A8)
A9: J2.N (A9), U1.24 (A9)
A10: J2.M (A10), U1.21 (A10)
A11: J2.L (A11), U1.23 (A11)
CLRRDYB: U4.1 (~R), U5.11 (PD5)
D0: J2.21 (D0), U1.11 (I/O0), U3.3 (D0)
D1: J2.20 (D1), U1.12 (I/O1), U3.4 (D1)
D2: J2.19 (D2), U1.13 (I/O2), U3.7 (D2)
D3: J2.18 (D3), U1.15 (I/O3), U3.8 (D3)
D4: J2.17 (D4), U1.16 (I/O4), U3.13 (D4)
D5: J2.16 (D5), U1.17 (I/O5), U3.14 (D5)
D6: J2.15 (D6), U1.18 (I/O6), U3.17 (D6)
D7: J2.14 (D7), U1.19 (I/O7), U3.18 (D7)
EXROMB: J1.2, J2.9 (#EXROM), U1.2 (A12)
GND: C1.2, C2.2, C3.2, C4.2, C5.2, C6.2, D1.2 (A), D2.2 (A), J1.3, J2.1 (GND), J2.22 (GND), J2.A (GND), J2.Z (GND), J3.4 (GND), J3.SH (Shield), U1.14 (GND), U2.4, U2.5, U2.7 (GND), U2.9, U2.10, U2.12, U2.13, U3.10 (GND), U4.7 (GND), U4.11 (C), U4.12 (D), U5.8 (GND), U5.22 (GND)
IO1B: J2.7 (#IO1), U2.1
KB0: U3.2 (Q0), U5.23 (PC0)
KB1: U3.5 (Q1), U5.24 (PC1)
KB2: U3.6 (Q2), U5.25 (PC2)
KB3: U3.9 (Q3), U5.26 (PC3)
KB4: U3.12 (Q4), U5.27 (PC4)
KB5: U3.15 (Q5), U5.28 (PC5)
KB6: U3.16 (Q6), U5.14 (PB0)
KB7: U3.19 (Q7), U5.15 (PB1)
unnamed: D1.1 (K), J3.2 (D-), R2.1, R3.1
unnamed: D2.1 (K), J3.3 (D+), R1.1
unnamed: U2.3, U3.11 (Cp), U4.3 (C)
unnamed: R1.2, U5.4 (PD2)
unnamed: R2.2, U5.5 (PD3)
unnamed: C5.1, U5.9 (XTAL1/PB6), Y1.2
unnamed: C6.1, U5.10 (XTAL2/PB7), Y1.1
RDY: U4.5 (Q), U5.6 (PD4)
ROMLB: J2.11 (#ROML), U1.20 (~CE), U1.22 (~OE)
RWB: J2.5 (R/#W), U2.2
VCC: C1.1, C2.1, C3.1, C4.1, J1.1, J2.2 (+5V), J2.3 (+5V), J2.8 (#GAME), R3.2, U1.27 (~WE), U1.28 (VCC), U2.14 (VCC), U3.1 (~Mr), U3.20 (VCC), U4.2 (D), U4.4 (~S), U4.10 (~S), U4.13 (~R), U4.14 (VCC), U5.1 (~RESET/PC6), U5.7 (VCC), U5.20 (AVCC)

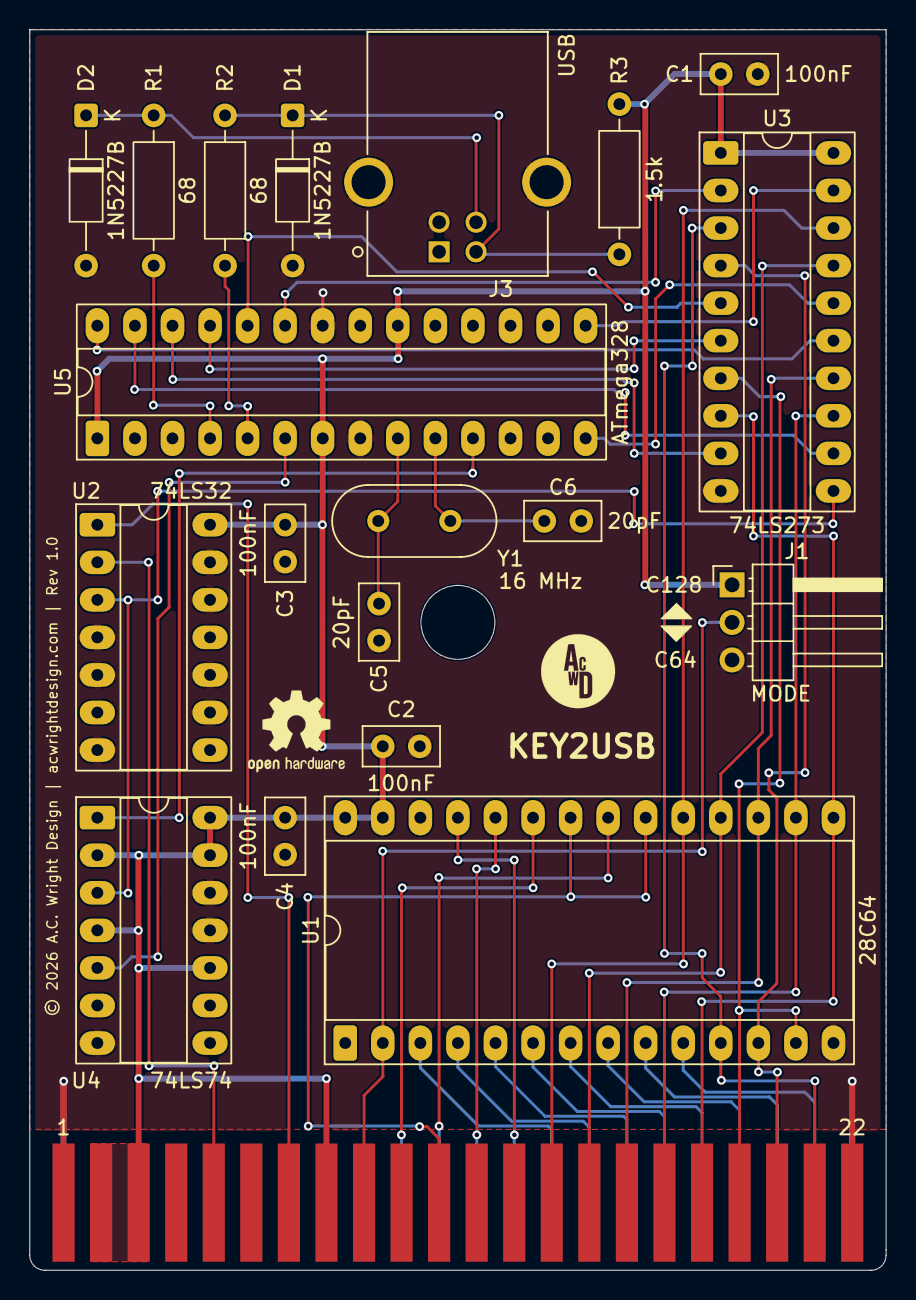
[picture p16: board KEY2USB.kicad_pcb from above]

Board: 2 copper layers, 57.9 x 83.9 mm, 20 parts (0 on the bottom side), 43 nets.

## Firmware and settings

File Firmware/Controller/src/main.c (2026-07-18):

/* =============================================================================
 *  KEY2USB - ATmega328/328P controller firmware
 * =============================================================================
 *  Reads C64/C128 key events from the 74LS273 latch (raised by the RDY flag),
 *  translates keyID -> USB HID usage, and reports them as a USB HID boot
 *  keyboard using V-USB (low-speed USB 1.1, software stack).
 *
 *  The two firmware halves share only the event byte; see src/protocol.h.
 */

#include <avr/io.h>
#include <avr/interrupt.h>
#include <avr/pgmspace.h>
#include <avr/wdt.h>
#include <util/delay.h>

#include "usbdrv.h"
#include "protocol.h"
#include "keymap.h"

/* --------------------------------------------------------------------------
 *  HID report descriptor: standard 8-byte boot keyboard
 *  [modifiers][reserved][keycode x6]
 * -------------------------------------------------------------------------- */
PROGMEM const char usbHidReportDescriptor[USB_CFG_HID_REPORT_DESCRIPTOR_LENGTH] = {
    0x05, 0x01,        /* Usage Page (Generic Desktop)          */
    0x09, 0x06,        /* Usage (Keyboard)                      */
    0xA1, 0x01,        /* Collection (Application)              */
    0x05, 0x07,        /*   Usage Page (Keyboard/Keypad)        */
    0x19, 0xE0,        /*   Usage Minimum (LeftControl)         */
    0x29, 0xE7,        /*   Usage Maximum (RightGUI)            */
    0x15, 0x00,        /*   Logical Minimum (0)                 */
    0x25, 0x01,        /*   Logical Maximum (1)                 */
    0x75, 0x01,        /*   Report Size (1)                     */
    0x95, 0x08,        /*   Report Count (8)                    */
    0x81, 0x02,        /*   Input (Data,Var,Abs) - modifier byte*/
    0x95, 0x01,        /*   Report Count (1)                    */
    0x75, 0x08,        /*   Report Size (8)                     */
    0x81, 0x01,        /*   Input (Const) - reserved byte       */
    0x95, 0x06,        /*   Report Count (6)                    */
    0x75, 0x08,        /*   Report Size (8)                     */
    0x15, 0x00,        /*   Logical Minimum (0)                 */
    0x25, 0x65,        /*   Logical Maximum (101)               */
    0x05, 0x07,        /*   Usage Page (Keyboard/Keypad)        */
    0x19, 0x00,        /*   Usage Minimum (0)                   */
    0x29, 0x65,        /*   Usage Maximum (101)                 */
    0x81, 0x00,        /*   Input (Data,Array) - 6 key slots    */
    0xC0               /* End Collection                        */
};

/* --------------------------------------------------------------------------
 *  Key state and report
 * -------------------------------------------------------------------------- */
static uint8_t reportBuffer[8];    /* what we transmit                        */
static uint8_t modifiers;          /* current modifier bitmap                 */
static uint8_t keys[6];            /* currently-held non-modifier HID usages  */
static uint8_t reportDirty;        /* set when the report needs (re)sending   */

static uint8_t idleRate;           /* HID idle rate, in 4 ms units (0 = off)  */

static void keyDown(uint8_t usage)
{
    uint8_t i;
    if (usage >= 0xE0 && usage <= 0xE7) {         /* modifier */
        modifiers |= (uint8_t)(1 << (usage - 0xE0));
        return;
    }
    for (i = 0; i < 6; i++)                        /* already held? */
        if (keys[i] == usage) return;
    for (i = 0; i < 6; i++)                        /* find a free slot */
        if (keys[i] == 0) { keys[i] = usage; return; }
    /* all slots full: drop (n-key rollover limit) */
}

static void keyUp(uint8_t usage)
{
    uint8_t i;
    if (usage >= 0xE0 && usage <= 0xE7) {
        modifiers &= (uint8_t)~(1 << (usage - 0xE0));
        return;
    }
    for (i = 0; i < 6; i++)
        if (keys[i] == usage) { keys[i] = 0; return; }
}

static void buildReport(void)
{
    uint8_t i;
    reportBuffer[0] = modifiers;
    reportBuffer[1] = 0;
    for (i = 0; i < 6; i++)
        reportBuffer[2 + i] = keys[i];
}

/* --------------------------------------------------------------------------
 *  1 ms tick (Timer0 CTC) - drives the HID idle timer only
 * -------------------------------------------------------------------------- */
static volatile uint8_t msTick;    /* free-running millisecond counter        */

ISR(TIMER0_COMPA_vect)
{
    msTick++;
}

static void timer0Init(void)
{
    /* CTC, prescaler 64: 16 MHz / 64 / 250 = 1000 Hz */
    TCCR0A = (1 << WGM01);
    TCCR0B = (1 << CS01) | (1 << CS00);
    OCR0A  = 249;
    TIMSK0 = (1 << OCIE0A);
}

/* --------------------------------------------------------------------------
 *  V-USB control-transfer handler (HID class requests)
 * -------------------------------------------------------------------------- */
usbMsgLen_t usbFunctionSetup(uchar data[8])
{
    usbRequest_t *rq = (usbRequest_t *)data;

    if ((rq->bmRequestType & USBRQ_TYPE_MASK) == USBRQ_TYPE_CLASS) {
        switch (rq->bRequest) {
        case USBRQ_HID_GET_REPORT:            /* host wants the current state */
            buildReport();
            usbMsgPtr = (usbMsgPtr_t)reportBuffer;
            return sizeof(reportBuffer);
        case USBRQ_HID_GET_IDLE:
            usbMsgPtr = (usbMsgPtr_t)&idleRate;
            return 1;
        case USBRQ_HID_SET_IDLE:
            idleRate = rq->wValue.bytes[1];
            return 0;
        default:
            break;
        }
    }
    return 0;   /* ignore unknown requests */
}

/* --------------------------------------------------------------------------
 *  Port setup
 * -------------------------------------------------------------------------- */
static void ioInit(void)
{
    /* PC0..PC5 = latch KB0..KB5 (inputs, no pull-ups: 74LS273 drives them) */
    DDRC  &= (uint8_t)~0x3F;
    PORTC &= (uint8_t)~0x3F;
    /* PB0..PB1 = latch KB6..KB7 (inputs) */
    DDRB  &= (uint8_t)~0x03;
    PORTB &= (uint8_t)~0x03;
    /* PD4 = RDY (input, driven by 74LS74) */
    DDRD  &= (uint8_t)~(1 << RDY_PIN);
    PORTD &= (uint8_t)~(1 << RDY_PIN);
    /* PD5 = /CLRRDY (output, idle high) */
    DDRD  |= (1 << CLRRDY_PIN);
    PORTD |= (1 << CLRRDY_PIN);
}

int main(void)
{
    uint8_t lastIdle = 0;

    /* Guard against a watchdog reset loop: clear the flag and disable the WDT
     * before it can expire at its post-reset (16 ms) timeout. */
    MCUSR = 0;
    wdt_disable();

    ioInit();
    key2usb_clear_ready();          /* start with a clean latch flag */

    wdt_enable(WDTO_1S);

    /* Force a USB re-enumeration so the host always sees a fresh connect,
     * even though the 1.5k pull-up is hard-wired to +5V. V-USB drives the
     * data lines low during the "disconnect" window. */
    usbInit();
    usbDeviceDisconnect();
    for (uint8_t i = 0; i < 250; i++) {
        wdt_reset();
        _delay_ms(1);
    }
    usbDeviceConnect();

    timer0Init();
    sei();

    for (;;) {
        wdt_reset();
        usbPoll();

        /* Drain one key event per iteration (the 6502 paces its writes). */
        if (key2usb_event_ready()) {
            uint8_t ev    = key2usb_read_latch();
            key2usb_clear_ready();
            uint8_t usage = pgm_read_byte(&keymap[EV_KEYID(ev)]);
            if (usage != HID_NONE) {
                if (ev & EV_PRESSED) keyDown(usage);
                else                 keyUp(usage);
                reportDirty = 1;
            }
        }

        /* HID idle: resend the current report every idleRate*4 ms. */
        if (idleRate != 0) {
            uint8_t now = msTick;
            if ((uint8_t)(now - lastIdle) >= (uint8_t)(idleRate << 2)) {
                lastIdle = now;
                reportDirty = 1;
            }
        }

        if (reportDirty && usbInterruptIsReady()) {
            buildReport();
            usbSetInterrupt(reportBuffer, sizeof(reportBuffer));
            reportDirty = 0;
        }
    }
}

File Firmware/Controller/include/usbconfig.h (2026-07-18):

/* =============================================================================
 *  usbconfig.h - V-USB configuration for KEY2USB (HID boot keyboard)
 * =============================================================================
 *  Based on V-USB's usbconfig-prototype.h (c) OBJECTIVE DEVELOPMENT GmbH.
 *  Hardware: ATmega328/328P @ 16 MHz, D+ on PD2/INT0, D- on PD3.
 */
#ifndef __usbconfig_h_included__
#define __usbconfig_h_included__

/* ---------------------------- Hardware Config ---------------------------- */
#define USB_CFG_IOPORTNAME      D
#define USB_CFG_DMINUS_BIT      3        /* PD3 */
#define USB_CFG_DPLUS_BIT       2        /* PD2 = INT0 (required) */
#define USB_CFG_CLOCK_KHZ       (F_CPU/1000)   /* 16000 */
#define USB_CFG_CHECK_CRC       0

/* --------------------------- Functional Range ---------------------------- */
#define USB_CFG_HAVE_INTRIN_ENDPOINT    1   /* interrupt-in endpoint 1 for HID */
#define USB_CFG_HAVE_INTRIN_ENDPOINT3   0
#define USB_CFG_EP3_NUMBER              3
#define USB_CFG_IMPLEMENT_HALT          0
#define USB_CFG_SUPPRESS_INTR_CODE      0
#define USB_CFG_INTR_POLL_INTERVAL      10  /* ms; >= 10 for low speed */
#define USB_CFG_IS_SELF_POWERED         1   /* powered from the C64, VBUS N/C */
#define USB_CFG_MAX_BUS_POWER           0   /* draws nothing from the USB bus */
#define USB_CFG_IMPLEMENT_FN_WRITE      0
#define USB_CFG_IMPLEMENT_FN_READ       0
#define USB_CFG_IMPLEMENT_FN_WRITEOUT   0
#define USB_CFG_HAVE_FLOWCONTROL        0
#define USB_CFG_DRIVER_FLASH_PAGE       0
#define USB_CFG_LONG_TRANSFERS          0
#define USB_COUNT_SOF                   0
#define USB_CFG_CHECK_DATA_TOGGLING     0
#define USB_CFG_HAVE_MEASURE_FRAME_LENGTH   0
#define USB_USE_FAST_CRC                0

/* -------------------------- Device Description --------------------------- */
/* obdev's free shared VID/PID for HID class devices. See USB-IDs-for-free.txt.
 * PID 0x27db is the shared "HID keyboard" product ID for VID 0x16c0. */
#define USB_CFG_VENDOR_ID       0xc0, 0x16      /* 0x16c0 */
#define USB_CFG_DEVICE_ID       0xdb, 0x27      /* 0x27db - shared HID keyboard */
#define USB_CFG_DEVICE_VERSION  0x01, 0x00      /* 0.01 */

#define USB_CFG_VENDOR_NAME     'a','c','w','r','i','g','h','t'
#define USB_CFG_VENDOR_NAME_LEN 8
#define USB_CFG_DEVICE_NAME     'K','E','Y','2','U','S','B'
#define USB_CFG_DEVICE_NAME_LEN 7
/* #define USB_CFG_SERIAL_NUMBER   'N','o','n','e' */
/* #define USB_CFG_SERIAL_NUMBER_LEN   0 */

#define USB_CFG_DEVICE_CLASS        0       /* deferred to interface */
#define USB_CFG_DEVICE_SUBCLASS     0
#define USB_CFG_INTERFACE_CLASS     0x03    /* HID */
#define USB_CFG_INTERFACE_SUBCLASS  0x01    /* Boot */
#define USB_CFG_INTERFACE_PROTOCOL  0x01    /* Keyboard */
/* 45-byte in-only boot keyboard report descriptor (no LED output collection;
 * the board has no indicator LEDs). Must match usbHidReportDescriptor[]. */
#define USB_CFG_HID_REPORT_DESCRIPTOR_LENGTH    45

/* ------------------- Fine Control over USB Descriptors ------------------- */
/* Let the driver build device/config/string descriptors; the HID report
 * descriptor is provided by us (usbHidReportDescriptor[] in main.c) and its
 * length is advertised via USB_CFG_HID_REPORT_DESCRIPTOR_LENGTH above. */
#define USB_CFG_DESCR_PROPS_DEVICE                  0
#define USB_CFG_DESCR_PROPS_CONFIGURATION           0
#define USB_CFG_DESCR_PROPS_STRINGS                 0
#define USB_CFG_DESCR_PROPS_STRING_0                0
#define USB_CFG_DESCR_PROPS_STRING_VENDOR           0
#define USB_CFG_DESCR_PROPS_STRING_PRODUCT          0
#define USB_CFG_DESCR_PROPS_STRING_SERIAL_NUMBER    0
#define USB_CFG_DESCR_PROPS_HID                     0
#define USB_CFG_DESCR_PROPS_HID_REPORT              0
#define USB_CFG_DESCR_PROPS_UNKNOWN                 0

/* ----------------------- Optional MCU Description ------------------------ */
/* Defaults in usbdrv.h are correct for INT0 on the ATmega328/328P. */

#endif /* __usbconfig_h_included__ */

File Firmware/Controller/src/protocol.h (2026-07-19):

/* =============================================================================
 *  protocol.h - KEY2USB event-byte contract (ATmega side)
 * =============================================================================
 *  Mirror of the 6502 side (Firmware/Cart/Cart.inc). One byte is latched into
 *  the 74LS273 each time the 6502 writes to $DE00; the 74LS74 raises RDY.
 *
 *      bit 7      : 1 = key pressed (make), 0 = key released (break)
 *      bits 6..0  : keyID  (C64 matrix = col*8+row, 0..63; C128 ext = 64..;
 *                           joystick port 2 = 112..116, port 1 = 120..124)
 *
 *  Pin contract (verified against Hardware/KEY2USB.kicad_sch, U5):
 *      KB0..KB5 -> PC0..PC5      KB6..KB7 -> PB0..PB1
 *      RDY      -> PD4 (input)   /CLRRDY  -> PD5 (output, active low)
 *      USB D+   -> PD2/INT0      USB D-   -> PD3
 */
#ifndef KEY2USB_PROTOCOL_H
#define KEY2USB_PROTOCOL_H

#include <avr/io.h>

#define EV_PRESSED   0x80        /* bit 7 of the event byte */
#define EV_KEYID(b)  ((b) & 0x7F)

/* Joystick keyIDs (mirror of JOY2_BASE / JOY1_BASE in Cart/Cart.inc).
 * Contacts arrive as ordinary key events; the keymap decides what they type. */
#define JOY2_UP      112
#define JOY2_DOWN    113
#define JOY2_LEFT    114
#define JOY2_RIGHT   115
#define JOY2_FIRE    116
#define JOY1_UP      120
#define JOY1_DOWN    121
#define JOY1_LEFT    122
#define JOY1_RIGHT   123
#define JOY1_FIRE    124

#define RDY_PIN      PD4
#define CLRRDY_PIN   PD5

/* Reassemble the latched key byte from the two input ports. */
static inline uint8_t key2usb_read_latch(void)
{
    return (uint8_t)((PINC & 0x3F) | ((PINB & 0x03) << 6));
}

/* True while the 74LS74 says a fresh event is waiting in the latch. */
static inline uint8_t key2usb_event_ready(void)
{
    return (PIND & (1 << RDY_PIN)) != 0;
}

/* Pulse /CLRRDY low to clear the ready flag after consuming an event. */
static inline void key2usb_clear_ready(void)
{
    PORTD &= ~(1 << CLRRDY_PIN);
    /* 74LS74 async clear needs only nanoseconds; a couple of NOPs suffice. */
    __asm__ __volatile__("nop\n\tnop\n\tnop\n\tnop");
    PORTD |= (1 << CLRRDY_PIN);
}

#endif /* KEY2USB_PROTOCOL_H */

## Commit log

2026-07-18 Implement KEY2USB firmware: 6502 cartridge ROM + ATmega328 V-USB controller
    Cart ROM (cc65): dual C64/C128 autostart banks in one 8K image, splash
    screen (KEY2USB V1.0), CIA#1 matrix scan emitting make/break events to
    $DE00. Handles two autostart quirks found during bring-up: the C64 bank
    must run IOINIT/RAMTAS/RESTOR/CINT itself (autostart runs before KERNAL
    init), and both banks must explicitly program the VIC-II for a known
    40-column screen (the C128 function-ROM autostart runs before the
    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
    [Cart.cfg, fuses.cfg]
2026-07-18 Fix C128 native-mode key scanning and tidy firmware docs
    Move the 6502 keyboard-state array (prevstate/prevext) out of $C000 into
    zero page. Under the C128 external-function-ROM memory config, $C000-$FFFF
    is ROM, so the state writes were dropped and the scan emitted phantom
    events; zero page is RAM on both the C64 and C128.
    Gate the C128 extended-key ($D02F) scan behind a SCAN_EXTENDED build flag,
    disabled by default: it is experimental, unmapped on the controller side,
    and not needed for the standard 8x8 matrix.
    Clean up the firmware READMEs into forward-looking reference docs.
    [Cart.asm]
2026-07-19 Add joystick support for both ports (v1.1.0)
    Scan both joystick ports alongside the keyboard matrix and report
    contacts as ordinary key events. No hardware change is involved: both
    DE9 ports were already on CIA#1, port 2 on port A (the column drive)
    and port 1 on port B (the row read).
    Three firmware fixes found during hardware bring-up:
    - emit_event now preserves Y. process_column keeps its row index in Y
    across the call, while the pacing delay used Y as its own loop
    counter, so every event after the first in a column was emitted as
    keybase+1. Latent since v1.0 -- it needs two keys in one column to
    change within a single 10 ms scan, which is rare when typing but
    constant for a j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
    [Cart.asm, protocol.h]
2026-07-20 Add case files
    [Bottom.stl, Case.3mf, Top.stl]
2026-07-21 Add room for socket mounted ICs in Case Top
    [Case.3mf, Top.stl]
2026-07-22 Case improvements
    [Bottom.stl, Case.3mf, Top.stl]
2026-08-16 Add insert doc
2026-10-22 Firmware v1.2.0: fix RESTORE crash and stuck keys, add key2usbmon
    Cartridge:
    - RESTORE no longer crashes to BASIC. The C64 KERNAL enters the NMI
    vector with nothing pushed, but the handler popped A/X/Y; on the C128
    the CPU vectors read open bus under the function-ROM MMU config.
    RESTORE is now reported as keyID 126.
    - SYNC event ($7F) at reset and ~1/s while idle, so the controller can
    release any key it still holds.
    - Delays timed on CIA#1 timer B (CPU-speed independent), row reads
    repeat until stable, modifiers wrap the keys they modify.
    Controller:
    - Handle SYNC; map RESTORE to Page Up (VICE's RESTORE key).
    - Send every report twice: V-USB never re-sends a missed report.
    - Poll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
2026-10-22 Fix C128-mode video: set up the 8502 port before IOINIT does
    The C128 KERNAL calls an autostart function ROM from its ROM poll
    ($E242 -> $E26B) before IOINIT ($E109), in every KERNAL revision. The
    8502 port's DDR is still all-inputs, so $01 bit 2 floats high on real
    hardware and the VIC reads character shapes from RAM: a screen of
    striped garbage. x128 models those bits low, which hid it.
    The C128 bank now writes IOINIT's port values ($01 = $E3, then
    $00 = $2F) and clears the VIC-IIe registers nothing else initialises:
    sprites, VIC interrupts, and $D030 (2 MHz / test). Verified on a real
    C128 in native mode. The C64 bank differs from v1.2.0 only in its
    version number. Cartridge firmware v1.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
2026-10-22 Make the C128 extra-key scan the default; document C128 mode (v1.3.0)
    The C128 bank now scans the keypad, ESC, TAB, ALT, HELP, LINE FEED,
    NO SCROLL, cursor pad and the CAPS LOCK / 40/80 latches by default;
    `make EXTENDED=0` builds it without. The default image is byte-
    identical to the one verified on a real C128: a full 89-key sweep, the
    x128 checklist, and an idle soak.
    Docs: x128 setup (key table, keypad vs Numpad joystick, CRSR and latch
    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
2026-10-22 Update the kit insert for v1.3.0
    C128 owners may now choose the C128 jumper position for the full C128
    keyboard in x128; RUN/STOP + RESTORE works in VICE; a SHIFT LOCK row in
    troubleshooting; key2usbmon alongside key2usbtest.prg. The PDF is
    regenerated from the HTML (it predated the last HTML edit) and still
    fits on one letter page.
2026-10-22 Add key2usbtest128, a BASIC 7.0 test program for x128
    key2usbtest.prg cannot run in C128 mode: it is a C64 BASIC 2 program
    saved for $0801, while C128 BASIC starts at $1C01. key2usbtest128
    names the key x128 sees held from the KERNAL's own matrix code ($D4,
    the same numbering as the cartridge's keyIDs), so the keypad, HELP,
    ESC, ALT, LINE FEED, NO SCROLL and cursor pad are named exactly. It
    also shows the modifier flags ($D3: SHIFT, C=, CTRL, ALT, CAPS LOCK),
    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
2026-10-22 Document VICE's "Allow keyset joysticks" setting
    VICE's Numpad (Keypad) joystick device and keysets do nothing until
    Settings -> Joystick -> Allow keyset joysticks is ticked, and each
    emulator keeps its own copy of the setting. It was set in x64sc but
    not in x128, where the stick just typed keypad digits. The README,
    Controller README and kit insert now say so, and the x128 section
    spells out the per-session choice between the port-2 joystick and
    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

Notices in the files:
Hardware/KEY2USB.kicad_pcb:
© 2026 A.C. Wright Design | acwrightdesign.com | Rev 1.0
